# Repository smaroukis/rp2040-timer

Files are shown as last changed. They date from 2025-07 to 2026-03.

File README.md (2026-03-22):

# 10k-Hour-Timer-RP2040

An Eval Board for an RP2040 mcu + seven segment LED display + TM1638 driver + peripherals. 

## Project Structure

- `kicad/` - KiCad schematic and PCB design files
- `firmware/` - Firmware source code
- `datasheets/` - Component datasheets and documentation

## Hardware

This project uses the RP2040 microcontroller with supporting circuitry for power management, display drivers, and user interface components.
Note the firmware can be tested using a Raspberry Pi Pico board (original/v1 not Pico 2). 

## Getting Started

TODO - will post build log in the future.

## License

MIT License with other license files attached as used. 

## Hardware Revisions

### 2026-03-22 v1
Tagged commit: <link here>

Thanks to PCBWay for providing a partial discount which I put towards two pre-assemblied. Note that resistors R20 and R22 were populated with 220Ohms instead of 200Ohms as specified in the BOM. However these are just MOFSET gate protection resistors.

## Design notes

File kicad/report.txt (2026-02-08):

Plotted to '/home/spencer/Applications/KiCad/10k-Hour-Timer-RP2040/kicad/Fabrication_Outputs/2026-02-08-1134/10k-Hour-Timer-RP2040-F_Cu.gbr'.
Plotted to '/home/spencer/Applications/KiCad/10k-Hour-Timer-RP2040/kicad/Fabrication_Outputs/2026-02-08-1134/10k-Hour-Timer-RP2040-In1_Cu.gbr'.
Plotted to '/home/spencer/Applications/KiCad/10k-Hour-Timer-RP2040/kicad/Fabrication_Outputs/2026-02-08-1134/10k-Hour-Timer-RP2040-In2_Cu.gbr'.
Plotted to '/home/spencer/Applications/KiCad/10k-Hour-Timer-RP2040/kicad/Fabrication_Outputs/2026-02-08-1134/10k-Hour-Timer-RP2040-B_Cu.gbr'.
Plotted to '/home/spencer/Applications/KiCad/10k-Hour-Timer-RP2040/kicad/Fabrication_Outputs/2026-02-08-1134/10k-Hour-Timer-RP2040-F_Paste.gbr'.
Plotted to '/home/spencer/Applications/KiCad/10k-Hour-Timer-RP2040/kicad/Fabrication_Outputs/2026-02-08-1134/10k-Hour-Timer-RP2040-B_Paste.gbr'.
Plotted to '/home/spencer/Applications/KiCad/10k-Hour-Timer-RP2040/kicad/Fabrication_Outputs/2026-02-08-1134/10k-Hour-Timer-RP2040-F_Silkscreen.gbr'.
Plotted to '/home/spencer/Applications/KiCad/10k-Hour-Timer-RP2040/kicad/Fabrication_Outputs/2026-02-08-1134/10k-Hour-Timer-RP2040-B_Silkscreen.gbr'.
Plotted to '/home/spencer/Applications/KiCad/10k-Hour-Timer-RP2040/kicad/Fabrication_Outputs/2026-02-08-1134/10k-Hour-Timer-RP2040-F_Mask.gbr'.
Plotted to '/home/spencer/Applications/KiCad/10k-Hour-Timer-RP2040/kicad/Fabrication_Outputs/2026-02-08-1134/10k-Hour-Timer-RP2040-B_Mask.gbr'.
Plotted to '/home/spencer/Applications/KiCad/10k-Hour-Timer-RP2040/kicad/Fabrication_Outputs/2026-02-08-1134/10k-Hour-Timer-RP2040-Edge_Cuts.gbr'.
Created Gerber job file '/home/spencer/Applications/KiCad/10k-Hour-Timer-RP2040/kicad/Fabrication_Outputs/2026-02-08-1134/10k-Hour-Timer-RP2040-job.gbrjob'.
Info: Done.
Info: Done.

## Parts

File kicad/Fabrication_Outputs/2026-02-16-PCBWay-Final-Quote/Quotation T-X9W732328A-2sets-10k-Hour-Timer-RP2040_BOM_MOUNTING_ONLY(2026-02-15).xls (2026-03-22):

PCBWay Bom Quotation, Product No.:T-X9W732328A
Item # | *Designator | *Qty | Manufacturer | *Mfg Part # | Description / Value | Vendor Part # | *Package/Footprint | Your Instructions / Notes | *Unit Price(2 sets) | *Total | *Delivery Time | *Actual Purchase Mfg Part # | *PCBWay Note | Customer Reply | PCBWay Update
1 | C1 | 1 |  |  | 01A-USB『 』10n『 』Unpolarized capacitor |  | Capacitor_SMD:C_0603_1608Metric_Pad1.08x0.95mm_HandSolder『 』603 |  | $0.040 | $0.080 |  | CC0603KRX7R6BB103 |  | OK
2 | C2,C13,C15,C16,C18,C19,C21,C22,C24,C26,C28 | 11 |  |  | 01A-USB,05-MCU-XTAL-FLASH,06-MCU-IO,07-RTC,08-LED『 』100n『 』Unpolarized capacitor |  | Capacitor_SMD:C_0603_1608Metric_Pad1.08x0.95mm_HandSolder『 』603 |  | $0.006 | $0.132 |  | CC0603KRX7R9BB104 |  | OK
3 | C3,C4,C6,C25 | 4 |  | CL10A475KO8NNNC | Note for PCBA『 』02-DCDC,03-Charger,07-RTC『 』4.7u『 』Unpolarized capacitor | C19666 | Capacitor_SMD:C_0603_1608Metric_Pad1.08x0.95mm_HandSolder『 』603 | https://jlcpcb.com/partdetail/20375-CL10A475KO8NNNC/C19666 | $0.042 | $0.336
4 | C5 | 1 |  |  | 04-Batt-Prot『 』0.1u『 』Unpolarized capacitor |  | Capacitor_SMD:C_0603_1608Metric_Pad1.08x0.95mm_HandSolder『 』603 |  | $0.044 | $0.088 |  | CC0603KRX7R9BB104 |  | OK
5 | C7 | 1 |  |  | 02-DCDC『 』470n |  | Capacitor_SMD:C_0603_1608Metric_Pad1.08x0.95mm_HandSolder『 』603 |  | $0.118 | $0.236 |  | CC0603KRX7R8BB474 |  | OK
6 | C8 | 1 | Samsung Electro-Mechanics | CL10A226MQ8NRNC | 02-DCDC『 』22u『 』6.3V 22uF X5R ±20% 0603 Multilayer Ceramic Capacitors MLCC - SMD/SMT ROHS | LCSC『 』C59461 | Capacitor_SMD:C_0603_1608Metric_Pad1.08x0.95mm_HandSolder『 』603 | https://jlcpcb.com/partdetail/60514-CL10A226MQ8NRNC/C59461 | $0.172 | $0.344
7 | C9 | 1 |  |  | 02-DCDC『 』6.8p |  | Capacitor_SMD:C_0603_1608Metric_Pad1.08x0.95mm_HandSolder『 』603 |  | $0.033 | $0.066 |  | TCC0603COG6R8C500CT |  | OK
8 | C10,C11 | 2 |  |  | 05-MCU-XTAL-FLASH『 』15p『 』Unpolarized capacitor |  | Capacitor_SMD:C_0603_1608Metric_Pad1.08x0.95mm_HandSolder『 』603 |  | $0.023 | $0.092 |  | CC0603JRNPO9BN150 |  | OK
9 | C12 | 1 |  |  | 05-MCU-XTAL-FLASH『 』2.2u『 』Unpolarized capacitor |  | Capacitor_SMD:C_0603_1608Metric_Pad1.08x0.95mm_HandSolder『 』603 |  | $0.106 | $0.212 |  | CL10A225KP8NNNC |  | OK
10 | C14,C17,C20 | 3 |  |  | 05-MCU-XTAL-FLASH『 』1u『 』Unpolarized capacitor |  | Capacitor_SMD:C_0603_1608Metric_Pad1.08x0.95mm_HandSolder『 』603 |  | $0.022 | $0.132 |  | TCC0603X5R105K250CT |  | OK
11 | C23,C27 | 2 | Samsung Electro-Mechanics | CL31A107MQHNNNE | 08-LED『 』100u『 』Unpolarized capacitor | LCSC『 』C15008 | Capacitor_SMD:C_1206_3216Metric『 』1206 | https://lcsc.com/product-detail/Multilayer-Ceramic-Capacitors-MLCC-SMD-SMT_Samsung-Electro-Mechanics-CL31A107MQHNNNE_C15008.html | $0.264 | $1.056
12 | Y2 | 1 | Abracon LLC | ABS07AIG-32.768KHZ-7-T | 07-RTC『 』ABS07AIG-32.768KHZ-7-T『 』32.768 kHz ±20ppm 水晶振動子 7pF 80 kOhms 2-SMD、リードなし | Digikey『 』535-13350-1-ND | Crystal:Crystal_SMD_3215-2Pin_3.2x1.5mm『 』2-SMD（3.2x1.5） | https://www.digikey.jp/ja/products/detail/abracon-llc/ABS07AIG-32.768KHZ-7-T/5817604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 | $1.493 | $2.986 |  | ABS07AIG-32.768kHz-7-T |  | OK
13 | D4 | 1 | onsemi | SS14 (Generic) | 01A-Power-Mux『 』SS14『 』40V 1A Schottky Diode, SMA | Generic『 』C83852 | Diode_SMD:D_SMA『 』SMA(DO-214AC) | https://lcsc.com/product-detail/Schottky-Diodes_onsemi-SS14_C83852.html?s_z=n_ss14 | $0.255 | $0.510 |  | SS14 |  | OK
14 | D3 | 1 | Nexperia | PMEG1020EA,115 | 01A-Power-Mux『 』SOD-323『 』10V 460mV@2A 2A SOD-323 Schottky Diodes ROHS | LCSC『 』C426863 | Diode_SMD:D_SOD-323_HandSoldering『 』SOD-323 | https://lcsc.com/product-detail/Schottky-Diodes_Nexperia-PMEG1020EA-115_C426863.html | $0.429 | $0.858
15 | D1 | 1 | Hubei KENTO Elec | KT-0805G | 01A-Power-Mux『 』BATT『 』Light emitting diode, green | LCSC『 』C2297 | LED_SMD:LED_0805_2012Metric『 』805 | https://lcsc.com/product-detail/LED-Indication-Discrete_Hubei-KENTO-Elec-KT-0805G_C2297.html?s_z=n_KT-0805G | $0.051 | $0.102
16 | D2 | 1 | Hubei KENTO Elec | KT-0805G | 01A-Power-Mux『 』5V『 』Light emitting diode, green | LCSC『 』C2297 | LED_SMD:LED_0805_2012Metric『 』805 | https://lcsc.com/product-detail/LED-Indication-Discrete_Hubei-KENTO-Elec-KT-0805G_C2297.html?s_z=n_KT-0805G | $0.051 | $0.102
17 | D5 | 1 | Hubei KENTO Elec | KT-0805G | 03-Charger『 』GRN/DONE『 』Light emitting diode, green | LCSC『 』C2297 | LED_SMD:LED_0805_2012Metric『 』805 | https://lcsc.com/product-detail/LED-Indication-Discrete_Hubei-KENTO-Elec-KT-0805G_C2297.html?s_z=n_KT-0805G | $0.051 | $0.102
18 | D6 | 1 | Foshan NationStar Optoelectronics | NCD0805R1 | 03-Charger『 』RED/CHG『 』25mA 67mcd~195mcd -30℃~+85℃ 615nm~630nm Discrete Diode Red 130° 65mW 1.6V~2.6V 0805 LED Indication - Discrete ROHS | LCSC『 』C84256 | LED_SMD:LED_0805_2012Metric『 』805 | https://lcsc.com/product-detail/Light-Emitting-Diodes-LED_Foshan-NationStar-Optoelectronics-NCD0805R1_C84256.html | $0.040 | $0.080
19 | D8 | 1 | Hubei KENTO Elec | KT-0805G | 01A-Power-Mux『 』3V3『 』Light emitting diode | LCSC『 』C2297 | LED_SMD:LED_0805_2012Metric『 』805 | https://lcsc.com/product-detail/LED-Indication-Discrete_Hubei-KENTO-Elec-KT-0805G_C2297.html?s_z=n_KT-0805G | $0.051 | $0.102
20 | D9 | 1 | Foshan NationStar Optoelectronics | NCD0805R1 | 06-MCU-IO『 』RED/USER『 』25mA 67mcd~195mcd -30℃~+85℃ 615nm~630nm Discrete Diode Red 130° 65mW 1.6V~2.6V 0805 LED Indication - Discrete ROHS | LCSC『 』C84256 | LED_SMD:LED_0805_2012Metric『 』805 | https://lcsc.com/product-detail/Light-Emitting-Diodes-LED_Foshan-NationStar-Optoelectronics-NCD0805R1_C84256.html | $0.040 | $0.080
21 | D10 | 1 | Foshan NationStar Optoelectronics | NCD0805R1 | 07-RTC『 』RED/INT『 』25mA 67mcd~195mcd -30℃~+85℃ 615nm~630nm Discrete Diode Red 130° 65mW 1.6V~2.6V 0805 LED Indication - Discrete ROHS | LCSC『 』C84256 | LED_SMD:LED_0805_2012Metric『 』805 | https://lcsc.com/product-detail/Light-Emitting-Diodes-LED_Foshan-NationStar-Optoelectronics-NCD0805R1_C84256.html | $0.040 | $0.080
22 | U6 | 1 | Raspberry Pi | SC0914(13) | 05-MCU-XTAL-FLASH『 』RP2040『 』A microcontroller by Raspberry Pi | Digikey | Package_DFN_QFN:QFN-56-1EP_7x7mm_P0.4mm_EP3.2x3.2mm『 』QFN-56-1EP | https://www.digikey.jp/en/products/detail/raspberry-pi/SC0914-13/14306010 | $3.280 | $6.560 | 7-10 Workdays |  |  | Yes, confirmed actual part number is SC0914(13)
23 | U7 | 1 | NXP | PCF8523T/1,118 | 07-RTC『 』PCF8523T『 』Realtime Clock/Calendar I2C Interface, SOIC-8 | LCSC『 』C2651516 | Package_SO:SOIC-8_3.9x4.9mm_P1.27mm『 』SOP-8 | https://lcsc.com/product-detail/Real-Time-Clocks_NXP-PCF8523T-1-118_C2651516.html?s_z=n_PCF8523T | $3.735 | $7.470
24 | U5 | 1 | Winbond Elec | W25Q128JVSIQ | 05-MCU-XTAL-FLASH『 』W25Q128JVS『 』128Mbit / 16MiB Serial Flash Memory, Standard/Dual/Quad SPI, 2.7-3.6V, SOIC-8 | Digikey『 』C113767 | Package_SO:SOIC-8_5.3x5.3mm_P1.27mm『 』SOIC-8 | https://www.digikey.jp/en/products/detail/winbond-electronics/W25Q128JVSIQ/5803943『 』https://lcsc.com/product-detail/NOR-FLASH_Winbond-Elec-W25Q128JVSIQ_C113767.html?s_z=n_W25Q128JVS%2520 | $2.103 | $4.206
25 | U3 | 1 | Texas Instruments | BQ29700DSER | 04-Batt-Prot『 』BQ29700DSER『 』Voltage and Current Protection for Single-Cell Li-Ion and Li-Polymer Batteries | Digikey | Package_SON:WSON-6_1.5x1.5mm_P0.5mm『 』6-WSON | https://www.digikey.jp/en/products/detail/texas-instruments/BQ29700DSER/5973173 | $1.277 | $2.554
26 | D7 | 1 | onsemi | BAT54CLT1G | 02-DCDC『 』BAT54C『 』30V 1 pair of common cathodes 800mV@100mA 200mA SOT-23 Schottky Diodes ROHS | LCSC『 』C14308 | Package_TO_SOT_SMD:SOT-23『 』SOT-23 | https://jlcpcb.com/partdetail/onsemi-BAT54CLT1G/C14308 | $0.080 | $0.160
27 | Q1,Q6 | 2 | Vishay | SI2301CDS-T1-GE3 | 01A-Power-Mux,07-RTC『 』PMOS『 』20V 3.1A 1.6W 142mΩ@2.5V,2.7A 1V@250uA 1 P-Channel SOT-23 MOSFETs ROHS | LCSC『 』C10487 | Package_TO_SOT_SMD:SOT-23『 』SOT-23 | https://lcsc.com/product-detail/MOSFETs_Vishay-Intertech-SI2301CDS-T1-GE3_C10487.html?s_z=n_SI2301CDS-T1-GE3 | $0.110 | $0.440
28 | Q2,Q3,Q4,Q5,Q7,Q8 | 6 | Alpha & Omega Semicon | AO3400A | 04-Batt-Prot,06-MCU-IO『 』AO3400A『 』30V Vds, 5.7A Id, N-Channel MOSFET, SOT-23 | LCSC『 』C20917 | Package_TO_SOT_SMD:SOT-23『 』SOT-23 | https://jlcpcb.com/partdetail/Alpha_OmegaSemicon-AO3400A/C20917 | $0.094 | $1.128
29 | U2 | 1 | Microchip Technology | MCP73831T-2ACI/OT | 03-Charger『 』MCP73831-2-OT『 』Single cell, Li-Ion/Li-Po charge management controller, 4.20V, Tri-State Status Output, in SOT23-5 package | Digikey | Package_TO_SOT_SMD:SOT-23-5『 』SOT23-5 | https://www.digikey.jp/en/products/detail/microchip-technology/MCP73831T-2ACI-OT/964301 | $0.734 | $1.468
30 | U4 | 1 | Texas Instruments | TLV62568DBVR | 02-DCDC『 』TLV62568DBVR『 』IC REG BUCK ADJ 1A SOT23-5 | Digikey | Package_TO_SOT_SMD:SOT-23-5『 』SOT23-5 | https://www.digikey.jp/en/products/detail/texas-instruments/TLV62568DBVR/6588886 | $0.068 | $0.136
31 | FB1 | 1 | Murata | BLM18SP221SN1D | 01A-USB『 』BLM18SP221SN1D『 』Ferrite bead | Digikey | project footprints:BLM18SP221SN1D_BEADC1608X95N『 』603 | https://www.digikey.jp/en/products/detail/murata-electronics/BLM18SP221SN1D/12759416 | $1.088 | $2.176
32 | BZ2 | 1 | Murata | PKMCS0909E4000-R1 | DONT INCLUDE IN PCBA『 』06-MCU-IO『 』PKMCS0909E4000『 』Buzzers Transducer, Externally Driven Piezo 1.5 V 4kHz 65dB @ 1.5V, 10cm Surface Mount Solder Pads | Digikey | project footprints:Buzzer_SPKR_PKMCS0909E4000-R1 | https://www.digikey.jp/en/products/detail/murata-electronics/PKMCS0909E4000-R1/4878401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 | $1.213 | $2.426
33 | L1 | 1 | Cyntec | SDER041H-2R2MS | 02-DCDC『 』2.2uH『 』FIXED IND 2.2UH 3.1A 45MOHM SMD | Digikey | project footprints:IND_SDER041H-2R2MS『 』4mmx4mm | https://www.digikey.jp/en/products/detail/delta-electronics-cyntec/SDER041H-2R2MS/9761210 | $0.860 | $1.720 | 7-10 Workdays
34 | U10 | 1 | Titan Micro Electronics | TM1638 | 08-LED『 』TM1638『 』SOIC-28-300mil Digital Tube Drivers ROHS Seven Segment LED Driver | LCSC『 』C19187 | project footprints:SOIC127P1041X265-28N『 』SOIC-28-300mil | https://lcsc.com/product-detail/LED-Display-Drivers_TM-Shenzhen-Titan-Micro-Elec_C19187.html | $0.485 | $0.970
35 | Y1 | 1 | Abracon LLC | ABM8-272-T3 | 05-MCU-XTAL-FLASH『 』ABM8-272-T3『 』Four pin crystal, GND on pins 2 and 4 | LCSC『 』C20625731 | project footprints:XTAL_ABM8-272-T3『 』SMD3225-4P | https://lcsc.com/product-detail/Crystals_Abracon-LLC-ABM8-272-T3_C20625731.html?s_z=n_ABM8-272-T3%2520 | $1.095 | $2.190
36 | R4,R19,R21,R24,R25,R28,R34,R35,R36,R39,R40,R44,R45,R46,R47,R48,R49 | 17 |  |  | 01A-Power-Mux,05-MCU-XTAL-FLASH,06-MCU-IO『 』10K『 』Resistor |  | Resistor_SMD:R_0805_2012Metric_Pad1.20x1.40mm_HandSolder『 』805 |  | $0.004 | $0.136 |  | RC0805FR-0710KL
37 | R1,R2 | 2 |  |  | 01A-USB『 』5.1K『 』Resistor |  | Resistor_SMD:R_0805_2012Metric_Pad1.20x1.40mm_HandSolder『 』805 |  | $0.019 | $0.076 |  | 0805W8F5101T5E
38 | R3,R14,R23,R26,R32,R38,R41 | 7 |  |  | 02-DCDC,04-Batt-Prot,05-MCU-XTAL-FLASH,06-MCU-IO,07-RTC『 』1K『 』Resistor |  | Resistor_SMD:R_0805_2012Metric_Pad1.20x1.40mm_HandSolder『 』805 |  | $0.007 | $0.098 |  | RC0805FR-071KL
39 | R5,R7,R8,R18 | 4 |  |  | 01A-Power-Mux,03-Charger『 』2K『 』Resistor |  | Resistor_SMD:R_0805_2012Metric_Pad1.20x1.40mm_HandSolder『 』805 |  | $0.009 | $0.072 |  | 0805W8F2001T5E
40 | R6 | 1 |  |  | 03-Charger『 』3K『 』Resistor |  | Resistor_SMD:R_0805_2012Metric_Pad1.20x1.40mm_HandSolder『 』805 |  | $0.033 | $0.066 |  | 0805W8F3001T5E
41 | R9 | 1 |  |  | 04-Batt-Prot『 』0『 』Resistor |  | Resistor_SMD:R_0805_2012Metric_Pad1.20x1.40mm_HandSolder『 』805 |  | $0.038 | $0.076 |  | 0805W8F0000T5E |  | 0805W8F0000T5E
42 | R10 | 1 |  |  | 04-Batt-Prot『 』330『 』Resistor |  | Resistor_SMD:R_0805_2012Metric_Pad1.20x1.40mm_HandSolder『 』805 |  | $0.026 | $0.052 |  | 0805W8F3300T5E |  | 0805W8F3300T5E
43 | R11 | 1 |  |  | 04-Batt-Prot『 』2.2K『 』Resistor |  | Resistor_SMD:R_0805_2012Metric_Pad1.20x1.40mm_HandSolder『 』805 |  | $0.038 | $0.076 |  | RC0805FR-072K2L
44 | R12,R13 | 2 |  |  | 04-Batt-Prot『 』5.1M『 』Resistor |  | Resistor_SMD:R_0805_2012Metric_Pad1.20x1.40mm_HandSolder『 』805 |  | $0.015 | $0.060 |  | 0805W8F5104T5E
45 | R15,R43 | 2 |  |  | 02-DCDC,07-RTC『 』100K『 』Resistor |  | Resistor_SMD:R_0805_2012Metric_Pad1.20x1.40mm_HandSolder『 』805 |  | $0.012 | $0.048 |  | 0805W8F1003T5E
46 | R16 | 1 |  |  | 02-DCDC『 』200K『 』Resistor |  | Resistor_SMD:R_0805_2012Metric_Pad1.20x1.40mm_HandSolder『 』805 |  | $0.024 | $0.048 |  | 0805W8F2003T5E
47 | R17 | 1 |  |  | 02-DCDC『 』44.2K『 』Resistor |  | Resistor_SMD:R_0805_2012Metric_Pad1.20x1.40mm_HandSolder『 』805 |  | $0.150 | $0.300 |  | 0805W8F4422T5E
48 | R20,R22 | 2 |  |  | 06-MCU-IO『 』200『 』Resistor |  | Resistor_SMD:R_0805_2012Metric_Pad1.20x1.40mm_HandSolder『 』805 |  | $0.018 | $0.072 |  | 0805W8F2200T5E |  | 0805W8F2200T5E
49 | R27,R29 | 2 |  |  | 06-MCU-IO『 』27『 』Resistor |  | Resistor_SMD:R_0805_2012Metric_Pad1.20x1.40mm_HandSolder『 』805 |  | $0.012 | $0.048 |  | 0805W8F270JT5E |  | 0805W8F270JT5E
50 | R30,R31 | 2 |  |  | 05-MCU-XTAL-FLASH『 』100『 』Resistor |  | Resistor_SMD:R_0805_2012Metric_Pad1.20x1.40mm_HandSolder『 』805 |  | $0.017 | $0.068 |  | 0805W8F1000T5E |  | 0805W8F1000T5E
51 | R33 | 1 |  |  | 05-MCU-XTAL-FLASH『 』1『 』Resistor |  | Resistor_SMD:R_0805_2012Metric_Pad1.20x1.40mm_HandSolder『 』805 |  |  |  |  |  | [DNP不要贴]; | Do Not Populate
52 | R37,R42 | 2 |  |  | 06-MCU-IO,07-RTC『 』470『 』Resistor |  | Resistor_SMD:R_0805_2012Metric_Pad1.20x1.40mm_HandSolder『 』805 |  | $0.016 | $0.064 |  | 0805W8F4700T5E |  | 0805W8F4700T5E
 |  |  |  |  |  |  |  |  | Component Cost | $42.74

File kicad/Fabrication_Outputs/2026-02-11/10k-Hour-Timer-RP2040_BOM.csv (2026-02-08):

Subsystem | Reference | Lab_In_Stock | Value | DNP | Exclude from BOM | Exclude from Board | Footprint | Description | Manufacturer | MPN | Supplier 1 | Supplier 1 URL | Supplier 1 SKU | Package | Supplier 2 URL | Supplier 2 | Supplier 2 SKU
 | BOM1 |  | JST PH 2.0mm Connector Kit | DNP | Excluded from BOM | Excluded from board |  | For Board Auxiliary order items - connectors, batteries, etc |  |  | Digikey | https://www.digikey.jp/en/products/detail/adafruit-industries-llc/4422/11497499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
 | BOM2 |  | Crimp Pliers for JST-PH connectors | DNP | Excluded from BOM | Excluded from board |  | Micro terminal crimper down to 1.0mm barrel width. Works well for JST-PH - use the 1.4mm or 1.6mm barrel size. | Engineer | PA-09 | Amazon | https://www.amazon.co.jp/-/en/Engineer-Precision-Crimping-Terminals-PA-09/dp/B002AVVO7K/ref=sr_1_2
 | BOM3 |  | Coin Vibration Motor 3V | DNP | Excluded from BOM | Excluded from board |  | 9000rpm Flat Vibration Motor 3V Vibration Motors ROHS 6mm | Leader | LCM0720A3134F | LCSC | https://lcsc.com/product-detail/Vibration-Motors_LEADER-LCM0720A3134F_C2895081.html | C2895081
05-MCU-XTAL-FLASH | SW1 | Y | B3U-1100PM | DNP | Excluded from BOM | Excluded from board | Button_Switch_SMD:SW_SPST_B3U-1100P | SWITCH TACTILE SPST-NO 0.05A 12V | omron | B3U-1100PM | Digikey | https://www.digikey.jp/en/products/detail/omron-electronics-inc-emc-div/B3U-1100PM/3908607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 |  | SMD 4mmx2.5mm
04-Batt-Prot | SW6 | THS | SW_SPDT | DNP |  |  | Button_Switch_THT:SW_E-Switch_EG1271_SPDT | Switch, single pole double throw | E-Switch | EG1271 | Digikey | https://www.digikey.com/en/products/detail/e-switch/EG1271/251335
05-MCU-XTAL-FLASH | SW2 | Y | BOOTSEL | DNP |  |  | Button_Switch_THT:SW_PUSH_6mm | Push button switch, generic, two pins | (Generic)/TE | (Generic)/1825910-6 | (Generic)/Digikey | https://www.digikey.jp/en/products/detail/te-connectivity-alcoswitch-switches/1825910-6/1632536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
05-MCU-XTAL-FLASH | SW3 | Y | RESET | DNP |  |  | Button_Switch_THT:SW_PUSH_6mm | Push button switch, generic, two pins | (Generic)/TE | (Generic)/1825910-6 | (Generic)/Digikey | https://www.digikey.jp/en/products/detail/te-connectivity-alcoswitch-switches/1825910-6/1632536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
06-MCU-IO | SW4 | Y | USER_A | DNP |  |  | Button_Switch_THT:SW_PUSH_6mm | Push button switch, generic, two pins | (Generic)/TE | (Generic)/1825910-6 | (Generic)/Digikey | https://www.digikey.jp/en/products/detail/te-connectivity-alcoswitch-switches/1825910-6/1632536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 |  | PB_6x6
06-MCU-IO | SW5 | Y | USER_B_PWR | DNP |  |  | Button_Switch_THT:SW_PUSH_6mm | Push button switch, generic, two pins | (Generic)/TE | (Generic)/1825910-6 | (Generic)/Digikey | https://www.digikey.jp/en/products/detail/te-connectivity-alcoswitch-switches/1825910-6/1632536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 |  | PB_6x6
01A-USB | C1 | Y | 10n |  |  |  | Capacitor_SMD:C_0603_1608Metric_Pad1.08x0.95mm_HandSolder | Unpolarized capacitor | (Generic) | (Generic) | (Generic) |  |  | 0603
01A-USB,05-MCU-XTAL-FLASH,06-MCU-IO,07-RTC,08-LED | C2,C13,C15,C16,C18,C19,C21,C22,C24,C26,C28 | Y | 100n |  |  |  | Capacitor_SMD:C_0603_1608Metric_Pad1.08x0.95mm_HandSolder | Unpolarized capacitor | (Generic) | (Generic) | (Generic) |  |  | 0603
02-DCDC,03-Charger,07-RTC | C3,C4,C6,C25 | Y | 4.7u |  |  |  | Capacitor_SMD:C_0603_1608Metric_Pad1.08x0.95mm_HandSolder | Unpolarized capacitor | (Generic) | (Generic) | (Generic) | https://jlcpcb.com/partdetail/20375-CL10A475KO8NNNC/C19666 | C19666 | 0603
04-Batt-Prot | C5 | Y | 0.1u |  |  |  | Capacitor_SMD:C_0603_1608Metric_Pad1.08x0.95mm_HandSolder | Unpolarized capacitor | (Generic) | (Generic) | (Generic) |  |  | 0603
02-DCDC | C7 | Y | 470n |  |  |  | Capacitor_SMD:C_0603_1608Metric_Pad1.08x0.95mm_HandSolder |  | (Generic) | (Generic) | (Generic) |  |  | 0603
02-DCDC | C8 |  | 22u |  |  |  | Capacitor_SMD:C_0603_1608Metric_Pad1.08x0.95mm_HandSolder | 6.3V 22uF X5R ±20% 0603 Multilayer Ceramic Capacitors MLCC - SMD/SMT ROHS | Samsung Electro-Mechanics | CL10A226MQ8NRNC | LCSC | https://jlcpcb.com/partdetail/60514-CL10A226MQ8NRNC/C59461 | C59461 | 0603
02-DCDC | C9 | Y | 6.8p |  |  |  | Capacitor_SMD:C_0603_1608Metric_Pad1.08x0.95mm_HandSolder |  | (Generic) | (Generic) | (Generic) |  |  | 0603
05-MCU-XTAL-FLASH | C10,C11 | Y | 15p |  |  |  | Capacitor_SMD:C_0603_1608Metric_Pad1.08x0.95mm_HandSolder | Unpolarized capacitor | (Generic) | (Generic) | (Generic) |  |  | 0603
05-MCU-XTAL-FLASH | C12 | Y | 2.2u |  |  |  | Capacitor_SMD:C_0603_1608Metric_Pad1.08x0.95mm_HandSolder | Unpolarized capacitor | (Generic) | (Generic) | (Generic) |  |  | 0603
05-MCU-XTAL-FLASH | C14,C17,C20 | Y | 1u |  |  |  | Capacitor_SMD:C_0603_1608Metric_Pad1.08x0.95mm_HandSolder | Unpolarized capacitor | (Generic) | (Generic) | (Generic) |  |  | 0603
08-LED | C23,C27 |  | 100u |  |  |  | Capacitor_SMD:C_1206_3216Metric | Unpolarized capacitor | Samsung Electro-Mechanics | CL31A107MQHNNNE | LCSC | https://lcsc.com/product-detail/Multilayer-Ceramic-Capacitors-MLCC-SMD-SMT_Samsung-Electro-Mechanics-CL31A107MQHNNNE_C15008.html | C15008 | 1206
02-DCDC,04-Batt-Prot | J4,J10 | Y | S2B-PH-K-S_LF__SN_ | DNP |  |  | Connector_JST:JST_PH_S2B-PH-K_1x02_P2.00mm_Horizontal | CONN HEADER R/A 2POS 2MM | JST | S2B-PH-K-S | Digikey | https://www.digikey.jp/en/products/detail/jst-sales-america-inc/S2B-PH-K-S/926626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 |  | NON STANDARD-2 J.S.T.
07-RTC | J9,J11 | Y | Conn_01x02_Pin | DNP |  |  | Connector_PinHeader_2.54mm:PinHeader_1x02_P2.54mm_Vertical | Generic connector, single row, 01x02, script generated
05-MCU-XTAL-FLASH,06-MCU-IO | J1,J7,J8 | Y | Conn_01x03_Pin | DNP |  |  | Connector_PinHeader_2.54mm:PinHeader_1x03_P2.54mm_Vertical | Generic connector, single row, 01x03, script generated | (Embedded) | (Embedded) | (Embedded)
06-MCU-IO | J5 | Y | Conn_02x05_Counter_Clockwise | DNP |  |  | Connector_PinHeader_2.54mm:PinHeader_2x05_P2.54mm_Vertical | Generic connector, double row, 02x05, odd/even pin numbering scheme (row 1 odd numbers, row 2 even numbers), script generated (kicad-library-utils/schlib/autogen/connector/)
 | J6 | Y | Conn_02x08_Counter_Clockwise | DNP |  |  | Connector_PinHeader_2.54mm:PinHeader_2x08_P2.54mm_Vertical | Generic connector, double row, 02x08, odd/even pin numbering scheme (row 1 odd numbers, row 2 even numbers), script generated (kicad-library-utils/schlib/autogen/connector/)
07-RTC | Y2 |  | ABS07AIG-32.768KHZ-7-T |  |  |  | Crystal:Crystal_SMD_3215-2Pin_3.2x1.5mm | 32.768 kHz ±20ppm 水晶振動子 7pF 80 kOhms 2-SMD、リードなし | Abracon LLC | ABS07AIG-32.768KHZ-7-T | Digikey | https://www.digikey.jp/ja/products/detail/abracon-llc/ABS07AIG-32.768KHZ-7-T/5817604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 | 535-13350-1-ND | 2-SMD（3.2x1.5）
01A-Power-Mux | D4 |  | SS14 |  |  |  | Diode_SMD:D_SMA | 40V 1A Schottky Diode, SMA | onsemi | SS14 (Generic) | Generic | https://lcsc.com/product-detail/Schottky-Diodes_onsemi-SS14_C83852.html?s_z=n_ss14 | C83852 | SMA(DO-214AC)
01A-Power-Mux | D3 |  | SOD-323 |  |  |  | Diode_SMD:D_SOD-323_HandSoldering | 10V 460mV@2A 2A SOD-323 Schottky Diodes ROHS | Nexperia | PMEG1020EA,115 | LCSC | https://lcsc.com/product-detail/Schottky-Diodes_Nexperia-PMEG1020EA-115_C426863.html | C426863 | SOD-323
01A-Power-Mux,06-MCU-IO | JP2,JP4,JP7,JP9,JP11,JP13,JP16,JP17,JP18,JP19,JP20 |  | SolderJumper_2_Bridged |  | Excluded from BOM |  | Jumper:SolderJumper-2_P1.3mm_Bridged_RoundedPad1.0x1.5mm | Solder Jumper, 2-pole, closed/bridged |  | (Embedded)
01A-Power-Mux,01A-USB,07-RTC | JP1,JP3,JP5,JP6,JP10,JP12,JP21,JP22,JP23,JP24 |  | SolderJumper_2_Open |  | Excluded from BOM |  | Jumper:SolderJumper-2_P1.3mm_Open_RoundedPad1.0x1.5mm | Solder Jumper, 2-pole, open |  | (Embedded)
 | JP8 |  | SolderJumper_3_Bridged12 |  | Excluded from BOM |  | Jumper:SolderJumper-3_P1.3mm_Bridged12_RoundedPad1.0x1.5mm | 3-pole Solder Jumper, pins 1+2 closed/bridged
01A-Power-Mux | D1 |  | BATT |  |  |  | LED_SMD:LED_0805_2012Metric | Light emitting diode | Hubei KENTO Elec | KT-0805G | LCSC | https://lcsc.com/product-detail/LED-Indication-Discrete_Hubei-KENTO-Elec-KT-0805G_C2297.html?s_z=n_KT-0805G | C2297 | 0805
01A-Power-Mux | D2 |  | 5V |  |  |  | LED_SMD:LED_0805_2012Metric | Light emitting diode | Hubei KENTO Elec | KT-0805G | LCSC | https://lcsc.com/product-detail/LED-Indication-Discrete_Hubei-KENTO-Elec-KT-0805G_C2297.html?s_z=n_KT-0805G | C2297 | 0805
03-Charger | D5 |  | GRN/DONE |  |  |  | LED_SMD:LED_0805_2012Metric | Light emitting diode | Hubei KENTO Elec | KT-0805G | LCSC | https://lcsc.com/product-detail/LED-Indication-Discrete_Hubei-KENTO-Elec-KT-0805G_C2297.html?s_z=n_KT-0805G | C2297 | 0805
03-Charger | D6 |  | RED/CHG |  |  |  | LED_SMD:LED_0805_2012Metric | 25mA 67mcd~195mcd -30℃~+85℃ 615nm~630nm Discrete Diode Red 130° 65mW 1.6V~2.6V 0805 LED Indication - Discrete ROHS | Foshan NationStar Optoelectronics | NCD0805R1 | LCSC | https://lcsc.com/product-detail/Light-Emitting-Diodes-LED_Foshan-NationStar-Optoelectronics-NCD0805R1_C84256.html | C84256 | 0805
01A-Power-Mux | D8 |  | 3V3 |  |  |  | LED_SMD:LED_0805_2012Metric | Light emitting diode | Hubei KENTO Elec | KT-0805G | LCSC | https://lcsc.com/product-detail/LED-Indication-Discrete_Hubei-KENTO-Elec-KT-0805G_C2297.html?s_z=n_KT-0805G | C2297 | 0805
06-MCU-IO | D9 |  | RED/USER |  |  |  | LED_SMD:LED_0805_2012Metric | 25mA 67mcd~195mcd -30℃~+85℃ 615nm~630nm Discrete Diode Red 130° 65mW 1.6V~2.6V 0805 LED Indication - Discrete ROHS | Foshan NationStar Optoelectronics | NCD0805R1 | LCSC | https://lcsc.com/product-detail/Light-Emitting-Diodes-LED_Foshan-NationStar-Optoelectronics-NCD0805R1_C84256.html | C84256 | 0805
07-RTC | D10 |  | RED/INT |  |  |  | LED_SMD:LED_0805_2012Metric | 25mA 67mcd~195mcd -30℃~+85℃ 615nm~630nm Discrete Diode Red 130° 65mW 1.6V~2.6V 0805 LED Indication - Discrete ROHS | Foshan NationStar Optoelectronics | NCD0805R1 | LCSC | https://lcsc.com/product-detail/Light-Emitting-Diodes-LED_Foshan-NationStar-Optoelectronics-NCD0805R1_C84256.html | C84256 | 0805
05-MCU-XTAL-FLASH | U6 |  | RP2040 |  |  |  | Package_DFN_QFN:QFN-56-1EP_7x7mm_P0.4mm_EP3.2x3.2mm | A microcontroller by Raspberry Pi | Raspberry Pi | SC0914(13) | Digikey | https://www.digikey.jp/en/products/detail/raspberry-pi/SC0914-13/14306010 |  | QFN-56-1EP
07-RTC | U7 |  | PCF8523T |  |  |  | Package_SO:SOIC-8_3.9x4.9mm_P1.27mm | Realtime Clock/Calendar I2C Interface, SOIC-8 | NXP | PCF8523T/1,118 | LCSC | https://lcsc.com/product-detail/Real-Time-Clocks_NXP-PCF8523T-1-118_C2651516.html?s_z=n_PCF8523T | C2651516 | SOP-8
05-MCU-XTAL-FLASH | U5 |  | W25Q128JVS |  |  |  | Package_SO:SOIC-8_5.3x5.3mm_P1.27mm | 128Mbit / 16MiB Serial Flash Memory, Standard/Dual/Quad SPI, 2.7-3.6V, SOIC-8 | Winbond Elec | W25Q128JVSIQ | Digikey | https://www.digikey.jp/en/products/detail/winbond-electronics/W25Q128JVSIQ/5803943 |  | SOIC-8 | https://lcsc.com/product-detail/NOR-FLASH_Winbond-Elec-W25Q128JVSIQ_C113767.html?s_z=n_W25Q128JVS%2520 | LCSC | C113767
04-Batt-Prot | U3 |  | BQ29700DSER |  |  |  | Package_SON:WSON-6_1.5x1.5mm_P0.5mm | Voltage and Current Protection for Single-Cell Li-Ion and Li-Polymer Batteries | Texas Instruments | BQ29700DSER | Digikey | https://www.digikey.jp/en/products/detail/texas-instruments/BQ29700DSER/5973173 |  | 6-WSON
02-DCDC | D7 |  | BAT54C |  |  |  | Package_TO_SOT_SMD:SOT-23 | 30V 1 pair of common cathodes 800mV@100mA 200mA SOT-23 Schottky Diodes ROHS | onsemi | BAT54CLT1G | LCSC | https://jlcpcb.com/partdetail/onsemi-BAT54CLT1G/C14308 | C14308 | SOT-23
01A-Power-Mux,07-RTC | Q1,Q6 |  | PMOS |  |  |  | Package_TO_SOT_SMD:SOT-23 | 20V 3.1A 1.6W 142mΩ@2.5V,2.7A 1V@250uA 1 P-Channel SOT-23 MOSFETs ROHS | Vishay | SI2301CDS-T1-GE3 | LCSC | https://lcsc.com/product-detail/MOSFETs_Vishay-Intertech-SI2301CDS-T1-GE3_C10487.html?s_z=n_SI2301CDS-T1-GE3 | C10487 | SOT-23
04-Batt-Prot,06-MCU-IO | Q2,Q3,Q4,Q5,Q7,Q8 |  | AO3400A |  |  |  | Package_TO_SOT_SMD:SOT-23 | 30V Vds, 5.7A Id, N-Channel MOSFET, SOT-23 | Alpha & Omega Semicon | AO3400A | LCSC | https://jlcpcb.com/partdetail/Alpha_OmegaSemicon-AO3400A/C20917 | C20917 | SOT-23
03-Charger | U2 |  | MCP73831-2-OT |  |  |  | Package_TO_SOT_SMD:SOT-23-5 | Single cell, Li-Ion/Li-Po charge management controller, 4.20V, Tri-State Status Output, in SOT23-5 package | Microchip Technology | MCP73831T-2ACI/OT | Digikey | https://www.digikey.jp/en/products/detail/microchip-technology/MCP73831T-2ACI-OT/964301 |  | SOT23-5
02-DCDC | U4 |  | TLV62568DBVR |  |  |  | Package_TO_SOT_SMD:SOT-23-5 | IC REG BUCK ADJ 1A SOT23-5 | Texas Instruments | TLV62568DBVR | Digikey | https://www.digikey.jp/en/products/detail/texas-instruments/TLV62568DBVR/6588886 |  | SOT23-5
01A-USB | U1 |  | USBLC6-2SC6 | DNP | Excluded from BOM | Excluded from board | Package_TO_SOT_SMD:SOT-23-6 | Very low capacitance ESD protection diode, 2 data-line, SOT-23-6 | ST Microelectronics | USBLC6-2SC6 | LCSC | https://lcsc.com/product-detail/ESD-and-Surge-Protection-TVS-ESD_STMicroelectronics-USBLC6-2SC6_C7519.html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 | C7519
08-LED | U8,U9 | Y | FJ2481CH | DNP |  |  | project footprints:7-Seg-CC28-FJ2481CH | 4 digit 7 segment red LED, common cathode 0.28" height 2.54mm pitch | Shenzhen Zhihao Elec | FJ2481CH | LCSC | https://lcsc.com/product-detail/LED-Segment-Displays_Shenzhen-Zhihao-Elec-FJ2481CH_C10707.html | C10707
04-Batt-Prot | BT1 | Y | Battery_Cell | DNP |  |  | project footprints:Battery-Holder-BH-123A_37.5P_1.8D_MH | Battery Holder 1 Cells Polypropylene Tray | MYOUNG | BH-123A-A1CJ002 | LCSC
01A-USB | FB1 | Y | BLM18SP221SN1D |  |  |  | project footprints:BLM18SP221SN1D_BEADC1608X95N | Ferrite bead | Murata | BLM18SP221SN1D | Digikey | https://www.digikey.jp/en/products/detail/murata-electronics/BLM18SP221SN1D/12759416 |  | 0603
06-MCU-IO | BZ1 | Y | Buzzer D=9mm P=5mm | DNP |  |  | project footprints:Buzzer-TH_D9.6_P5 | 85dB Active (Built-in Driver Circuit) Electromagnetic Type 3kHz Plugin,D=9mm Buzzers ROHS | Jiangsu Huaneng Elec | HNB09A05 | LCSC | https://lcsc.com/product-detail/Buzzers_Jiangsu-Huaneng-Elec-HNB09A05_C96493.html | C96493 | BZ_THT_D9.6_P5
06-MCU-IO | BZ2 |  | PKMCS0909E4000 |  |  |  | project footprints:Buzzer_SPKR_PKMCS0909E4000-R1 | Buzzers Transducer, Externally Driven Piezo 1.5 V 4kHz 65dB @ 1.5V, 10cm Surface Mount Solder Pads | Murata | PKMCS0909E4000-R1 | Digikey | https://www.digikey.jp/en/products/detail/murata-electronics/PKMCS0909E4000-R1/4878401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
01A-USB | J3 | Y | USB4105-GF-A | DNP |  |  | project footprints:GCT_USB4105-GF-A | CONN RCP USB2.0 TYP C 24P SMD RA | GCT | USB4105-GF-A | Digikey | https://www.digikey.jp/en/products/detail/gct/USB4105-GF-A/11198441 | 2073-USB4105-GF-ACT-ND
02-DCDC | L1 |  | 2.2uH |  |  |  | project footprints:IND_SDER041H-2R2MS | FIXED IND 2.2UH 3.1A 45MOHM SMD | Cyntec | SDER041H-2R2MS | Digikey | https://www.digikey.jp/en/products/detail/delta-electronics-cyntec/SDER041H-2R2MS/9761210 |  | 4mmx4mm
05-MCU-XTAL-FLASH | J2 |  | JST_SH_SM03B | DNP |  |  | project footprints:JST_SH_SM03B-SRSS-TB_1x03-1MP_P1.00mm_Horizontal | Generic connectable mounting pin connector, single row, 01x03, script generated (kicad-library-utils/schlib/autogen/connector/) | JST | SM03B-SRSS-TB(LF)(SN) | LCSC | https://lcsc.com/product-detail/Wire-To-Board-Connector_JST-SM03B-SRSS-TB-LF-SN_C160403.html | C160403
 | H1,H2,H3,H4 | Y | MH-4.7mm |  | Excluded from BOM |  | project footprints:MountingHole_4.7mm | BOARD SUPRT SNAP FIT NYLON 4.7mm hole,Mounting Hole without connection | Keystone | 8834 | Digikey | https://www.digikey.jp/en/products/detail/keystone-electronics/8834/317168 |  | D4.7mm
08-LED | U10 | Y | TM1638 |  |  |  | project footprints:SOIC127P1041X265-28N | SOIC-28-300mil Digital Tube Drivers ROHS Seven Segment LED Driver | Titan Micro Electronics | TM1638 | LCSC | https://lcsc.com/product-detail/LED-Display-Drivers_TM-Shenzhen-Titan-Micro-Elec_C19187.html | C19187 | SOIC-28-300mil
01A-USB,04-Batt-Prot | TP1,TP13 |  | GND |  |  |  | project footprints:TestPoint_THTPad_D2.0mm_Drill1.0mm | test point |  | (Embedded)
01A-USB | TP2 |  | VBUS_IN |  |  |  | project footprints:TestPoint_THTPad_D2.0mm_Drill1.0mm | test point |  | (Embedded)
01A-USB | TP3 |  | VBUS |  |  |  | project footprints:TestPoint_THTPad_D2.0mm_Drill1.0mm | test point |  | (Embedded)
01A-Power-Mux | TP4 |  | VBAT |  |  |  | project footprints:TestPoint_THTPad_D2.0mm_Drill1.0mm | test point |  | (Embedded)
 | TP5 |  | U2_VDD |  |  |  | project footprints:TestPoint_THTPad_D2.0mm_Drill1.0mm | test point |  | (Embedded)
01A-Power-Mux | TP6 |  | VSW |  |  |  | project footprints:TestPoint_THTPad_D2.0mm_Drill1.0mm | test point |  | (Embedded)
 | TP7 |  | STAT |  |  |  | project footprints:TestPoint_THTPad_D2.0mm_Drill1.0mm | test point |  | (Embedded)
04-Batt-Prot | TP8 |  | BAT+ |  |  |  | project footprints:TestPoint_THTPad_D2.0mm_Drill1.0mm | test point |  | (Embedded)
04-Batt-Prot | TP9,TP15 |  | BAT- |  |  |  | project footprints:TestPoint_THTPad_D2.0mm_Drill1.0mm | test point |  | (Embedded)
04-Batt-Prot | TP10 |  | U3_V- |  |  |  | project footprints:TestPoint_THTPad_D2.0mm_Drill1.0mm | test point |  | (Embedded)
04-Batt-Prot | TP11 |  | DSG |  |  |  | project footprints:TestPoint_THTPad_D2.0mm_Drill1.0mm | test point |  | (Embedded)
 | TP12 |  | CHG |  |  |  | project footprints:TestPoint_THTPad_D2.0mm_Drill1.0mm | test point |  | (Embedded)
04-Batt-Prot | TP14 |  | Q23_D |  |  |  | project footprints:TestPoint_THTPad_D2.0mm_Drill1.0mm | test point |  | (Embedded)
 | TP16 |  | EN_CTL |  |  |  | project footprints:TestPoint_THTPad_D2.0mm_Drill1.0mm | test point |  | (Embedded)
 | TP17 |  | DC_SW |  |  |  | project footprints:TestPoint_THTPad_D2.0mm_Drill1.0mm | test point |  | (Embedded)
06-MCU-IO | TP18 |  | IOGate |  |  |  | project footprints:TestPoint_THTPad_D2.0mm_Drill1.0mm | test point |  | (Embedded)
 | TP19 |  | DCDC_EN |  |  |  | project footprints:TestPoint_THTPad_D2.0mm_Drill1.0mm | test point |  | (Embedded)
06-MCU-IO | TP20 |  | ADC1 |  |  |  | project footprints:TestPoint_THTPad_D2.0mm_Drill1.0mm | test point |  | (Embedded)
06-MCU-IO | TP21 |  | BTN_B |  |  |  | project footprints:TestPoint_THTPad_D2.0mm_Drill1.0mm | test point |  | (Embedded)
06-MCU-IO | TP22 |  | BTN_B_IN |  |  |  | project footprints:TestPoint_THTPad_D2.0mm_Drill1.0mm | test point |  | (Embedded)
 | TP23 |  | ADC0 |  |  |  | project footprints:TestPoint_THTPad_D2.0mm_Drill1.0mm | test point |  | (Embedded)
 | TP24 |  | INT_G |  |  |  | project footprints:TestPoint_THTPad_D2.0mm_Drill1.0mm | test point |  | (Embedded)
 | TP25 |  | INT_D |  |  |  | project footprints:TestPoint_THTPad_D2.0mm_Drill1.0mm | test point |  | (Embedded)
 | TP26 |  | LOAD |  |  |  | project footprints:TestPoint_THTPad_D2.0mm_Drill1.0mm | test point |  | (Embedded)
 | TP27 |  | FB |  |  |  | project footprints:TestPoint_THTPad_D2.0mm_Drill1.0mm | test point |  | (Embedded)
01A-USB | J12 |  | USB_C_Receptacle_USB2.0_16P | DNP | Excluded from BOM | Excluded from board | project footprints:USB_C_Receptacle_JAE_DX07S016JA1R1500 | USB 2.0-only 16P Type-C Receptacle connector | JAE Electronics | DX07S016JA1R1500 | LCSC | https://lcsc.com/product-detail/USB-Connectors_JAE-Electronics-DX07S016JA1R1500_C3197885.html | C3197885
05-MCU-XTAL-FLASH | Y1 |  | ABM8-272-T3 |  |  |  | project footprints:XTAL_ABM8-272-T3 | Four pin crystal, GND on pins 2 and 4 | Abracon LLC | ABM8-272-T3 | LCSC | https://lcsc.com/product-detail/Crystals_Abracon-LLC-ABM8-272-T3_C20625731.html?s_z=n_ABM8-272-T3%2520 | C20625731 | SMD3225-4P
01A-USB | R1,R2 |  | 5.1K |  |  |  | Resistor_SMD:R_0805_2012Metric_Pad1.20x1.40mm_HandSolder | Resistor | (Generic) | (Generic) | (Generic) |  |  | 0805
02-DCDC,04-Batt-Prot,05-MCU-XTAL-FLASH,06-MCU-IO,07-RTC | R3,R14,R23,R26,R32,R38,R41 |  | 1K |  |  |  | Resistor_SMD:R_0805_2012Metric_Pad1.20x1.40mm_HandSolder | Resistor | (Generic) | (Generic) | (Generic) |  |  | 0805
01A-Power-Mux,05-MCU-XTAL-FLASH,06-MCU-IO | R4,R19,R21,R24,R25,R28,R34,R35,R36,R39,R40,R44,R45,R46,R47,R48,R49 |  | 10K | DNP |  |  | Resistor_SMD:R_0805_2012Metric_Pad1.20x1.40mm_HandSolder | Resistor | (Generic) | (Generic) | (Generic) |  |  | 0805
01A-Power-Mux,03-Charger | R5,R7,R8,R18 |  | 2K |  |  |  | Resistor_SMD:R_0805_2012Metric_Pad1.20x1.40mm_HandSolder | Resistor | (Generic) | (Generic) | (Generic) |  |  | 0805
03-Charger | R6 |  | 3K |  |  |  | Resistor_SMD:R_0805_2012Metric_Pad1.20x1.40mm_HandSolder | Resistor | (Generic) | (Generic) | (Generic) |  |  | 0805
04-Batt-Prot | R9 |  | 0 |  |  |  | Resistor_SMD:R_0805_2012Metric_Pad1.20x1.40mm_HandSolder | Resistor | (Generic) | (Generic) | (Generic) |  |  | 0805
04-Batt-Prot | R10 |  | 330 |  |  |  | Resistor_SMD:R_0805_2012Metric_Pad1.20x1.40mm_HandSolder | Resistor | (Generic) | (Generic) | (Generic) |  |  | 0805
04-Batt-Prot | R11 |  | 2.2K |  |  |  | Resistor_SMD:R_0805_2012Metric_Pad1.20x1.40mm_HandSolder | Resistor | (Generic) | (Generic) | (Generic) |  |  | 0805
04-Batt-Prot | R12,R13 |  | 5.1M |  |  |  | Resistor_SMD:R_0805_2012Metric_Pad1.20x1.40mm_HandSolder | Resistor | (Generic) | (Generic) | (Generic) |  |  | 0805
02-DCDC,07-RTC | R15,R43 |  | 100K |  |  |  | Resistor_SMD:R_0805_2012Metric_Pad1.20x1.40mm_HandSolder | Resistor | (Generic) | (Generic) | (Generic) |  |  | 0805
02-DCDC | R16 |  | 200K |  |  |  | Resistor_SMD:R_0805_2012Metric_Pad1.20x1.40mm_HandSolder | Resistor | (Generic) | (Generic) | (Generic) |  |  | 0805
02-DCDC | R17 |  | 44.2K |  |  |  | Resistor_SMD:R_0805_2012Metric_Pad1.20x1.40mm_HandSolder | Resistor | (Generic) | (Generic) | (Generic) |  |  | 0805
06-MCU-IO | R20,R22 |  | 200 |  |  |  | Resistor_SMD:R_0805_2012Metric_Pad1.20x1.40mm_HandSolder | Resistor | (Generic) | (Generic) | (Generic) |  |  | 0805
06-MCU-IO | R27,R29 |  | 27 |  |  |  | Resistor_SMD:R_0805_2012Metric_Pad1.20x1.40mm_HandSolder | Resistor | (Generic) | (Generic) | (Generic) |  |  | 0805
05-MCU-XTAL-FLASH | R30,R31 |  | 100 |  |  |  | Resistor_SMD:R_0805_2012Metric_Pad1.20x1.40mm_HandSolder | Resistor | (Generic) | (Generic) | (Generic) |  |  | 0805
05-MCU-XTAL-FLASH | R33 |  | 1 |  |  |  | Resistor_SMD:R_0805_2012Metric_Pad1.20x1.40mm_HandSolder | Resistor | (Generic) | (Generic) | (Generic) |  |  | 0805
06-MCU-IO,07-RTC | R37,R42 |  | 470 |  |  |  | Resistor_SMD:R_0805_2012Metric_Pad1.20x1.40mm_HandSolder | Resistor | (Generic) | (Generic) | (Generic) |  |  | 0805

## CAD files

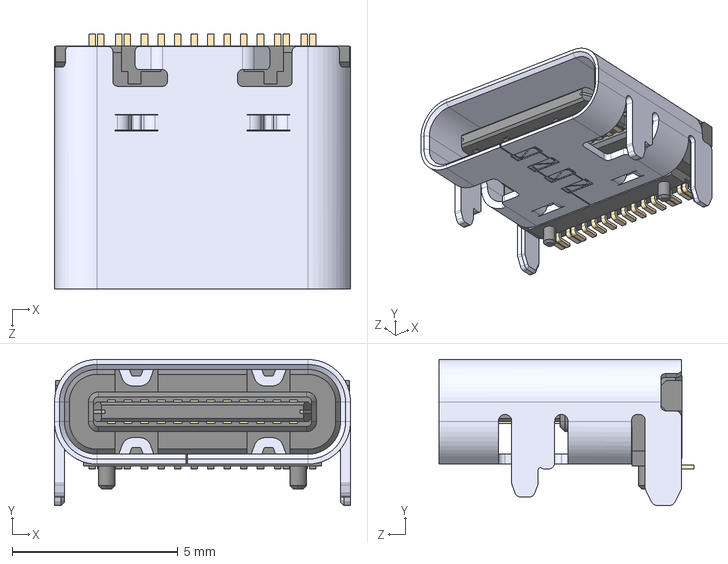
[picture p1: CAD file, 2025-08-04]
kicad/Project_Libraries/3dmodels/USB4105-GF-A.step
8.94 x 4.41 x 7.71 mm

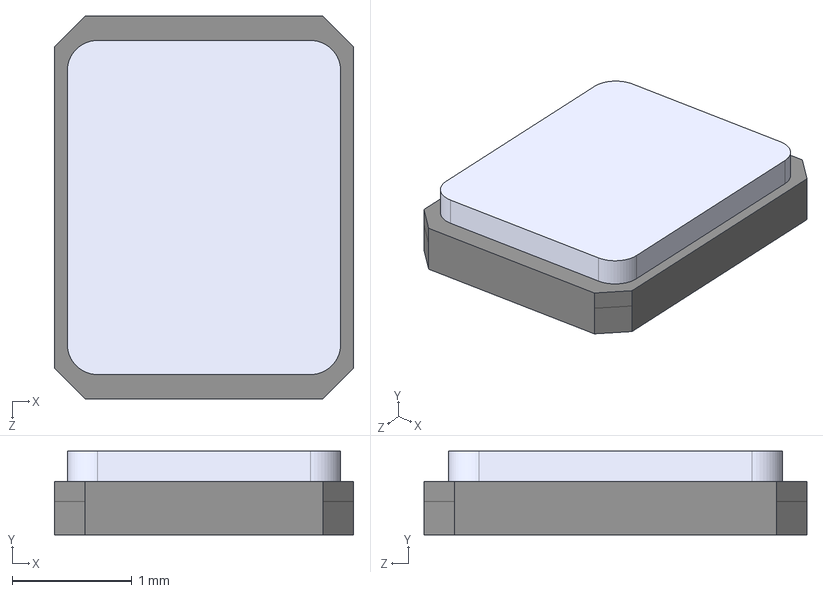
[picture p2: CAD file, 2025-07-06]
kicad/Project_Libraries/imports_source/ABM8_272_T3/ABM8-272-T3.step
2.50 x 0.7 x 3.20 mm

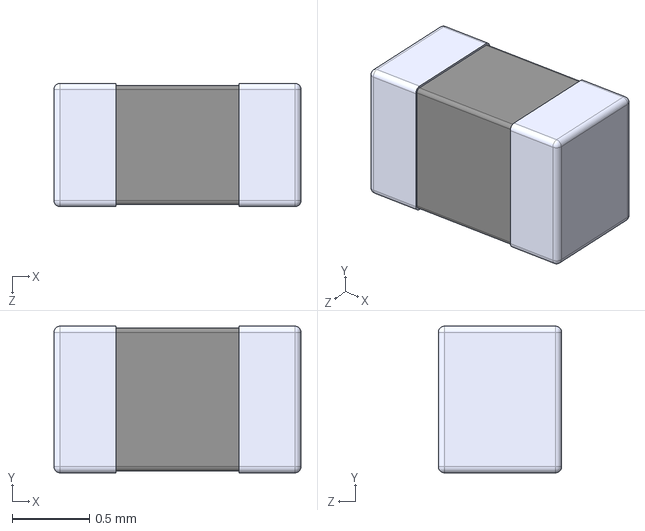
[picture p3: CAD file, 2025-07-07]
kicad/Project_Libraries/imports_source/BLM18PG221SN1D/BLM18PG221SN1D.step
1.60 x 0.95 x 0.8 mm

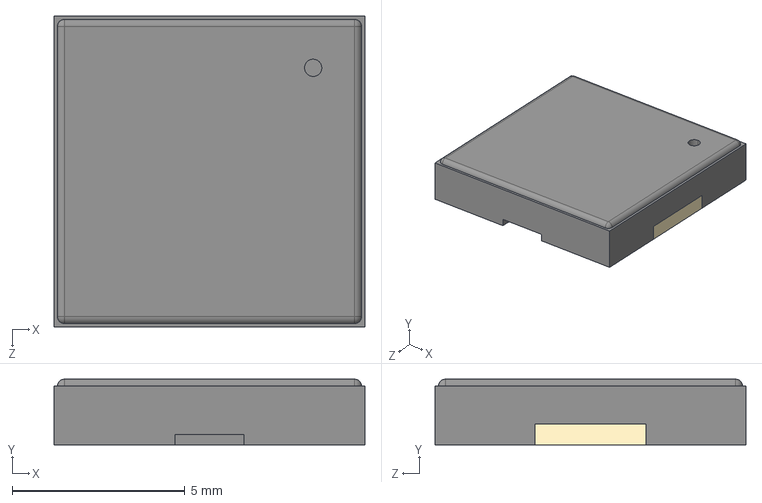
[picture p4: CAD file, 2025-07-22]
kicad/Project_Libraries/imports_source/PKMCS0909E4000_R1/PKMCS0909E4000-R1.step
9.00 x 1.90 x 9.00 mm

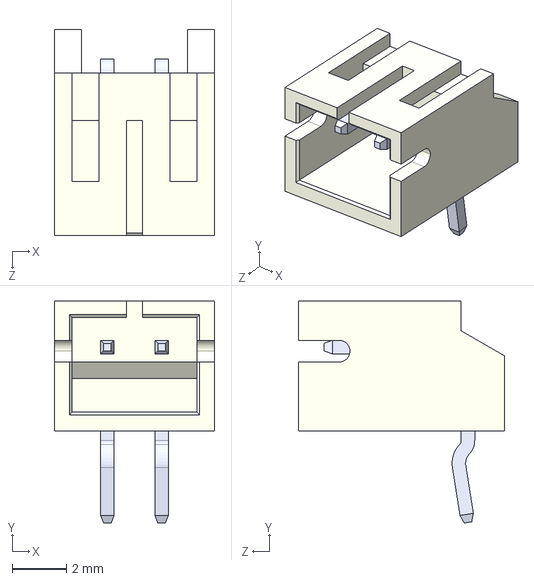
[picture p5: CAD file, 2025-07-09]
kicad/Project_Libraries/imports_source/S2B-PH-K-S_LF__SN_/S2B-PH-K-S_LF__SN_.step
5.90 x 8.18 x 7.60 mm

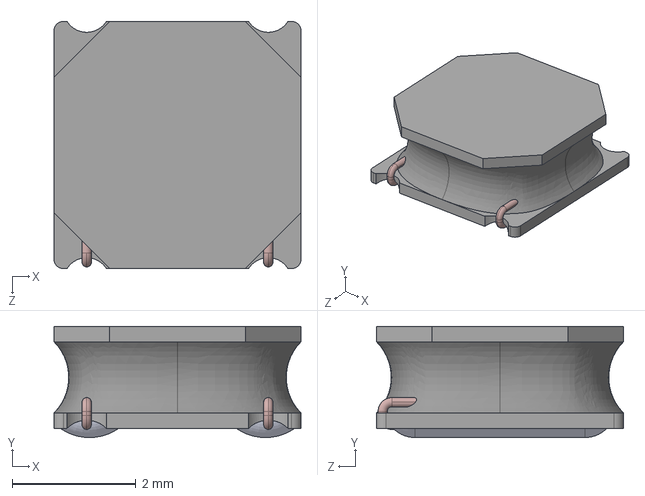
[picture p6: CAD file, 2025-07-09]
kicad/Project_Libraries/imports_source/SDER041H_2R2MS/SDER041H-2R2MS.step
4.00 x 1.80 x 4.00 mm

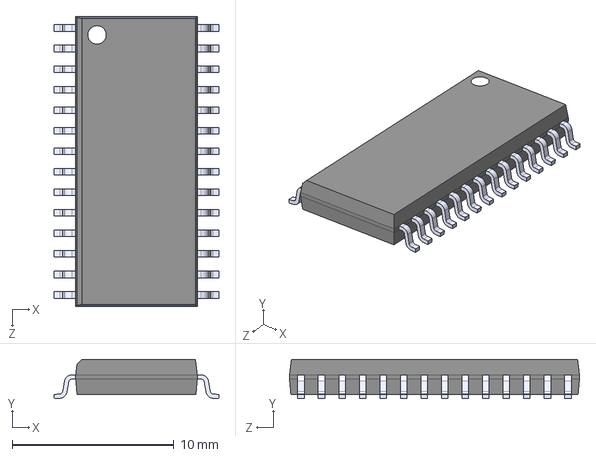
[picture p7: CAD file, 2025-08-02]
kicad/Project_Libraries/imports_source/TM1638/TM1638.step
10.2 x 2.44 x 17.9 mm

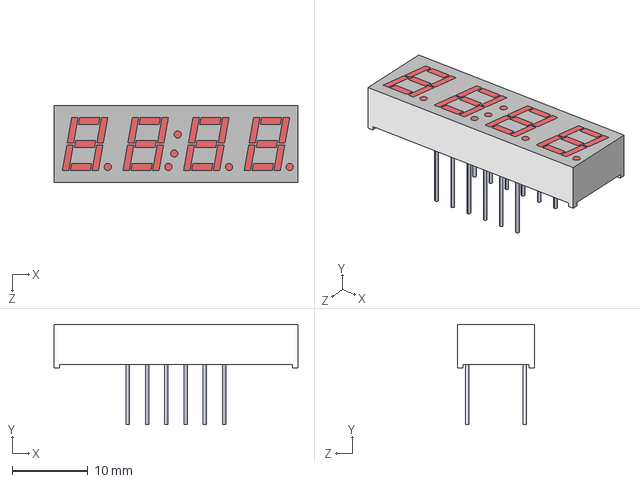
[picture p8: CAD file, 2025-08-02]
kicad/Project_Libraries/3dmodels/LDQ-M284RI--3DModel-STEP-510211.STEP
32.2 x 13.2 x 10.2 mm

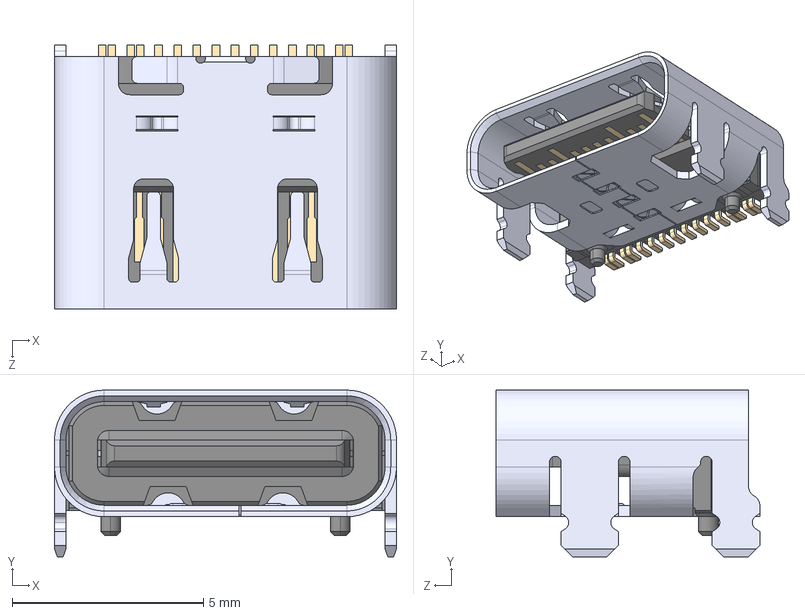
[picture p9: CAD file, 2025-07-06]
kicad/Project_Libraries/3dmodels/DX07S016JA1R1500--3DModel-STEP-1.STEP
8.94 x 4.36 x 6.90 mm

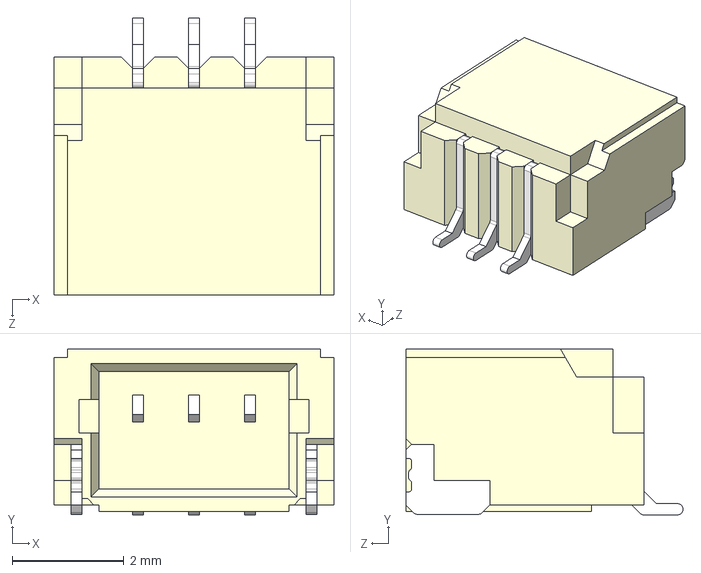
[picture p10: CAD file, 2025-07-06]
kicad/Project_Libraries/3dmodels/SM03B-SRSS-TB(LF)(SN)--3DModel-STEP-56544.STEP
5.00 x 2.96 x 4.95 mm

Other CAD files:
kicad/Project_Libraries/imports_source/BQ29700DSER/BQ29700DSER.step

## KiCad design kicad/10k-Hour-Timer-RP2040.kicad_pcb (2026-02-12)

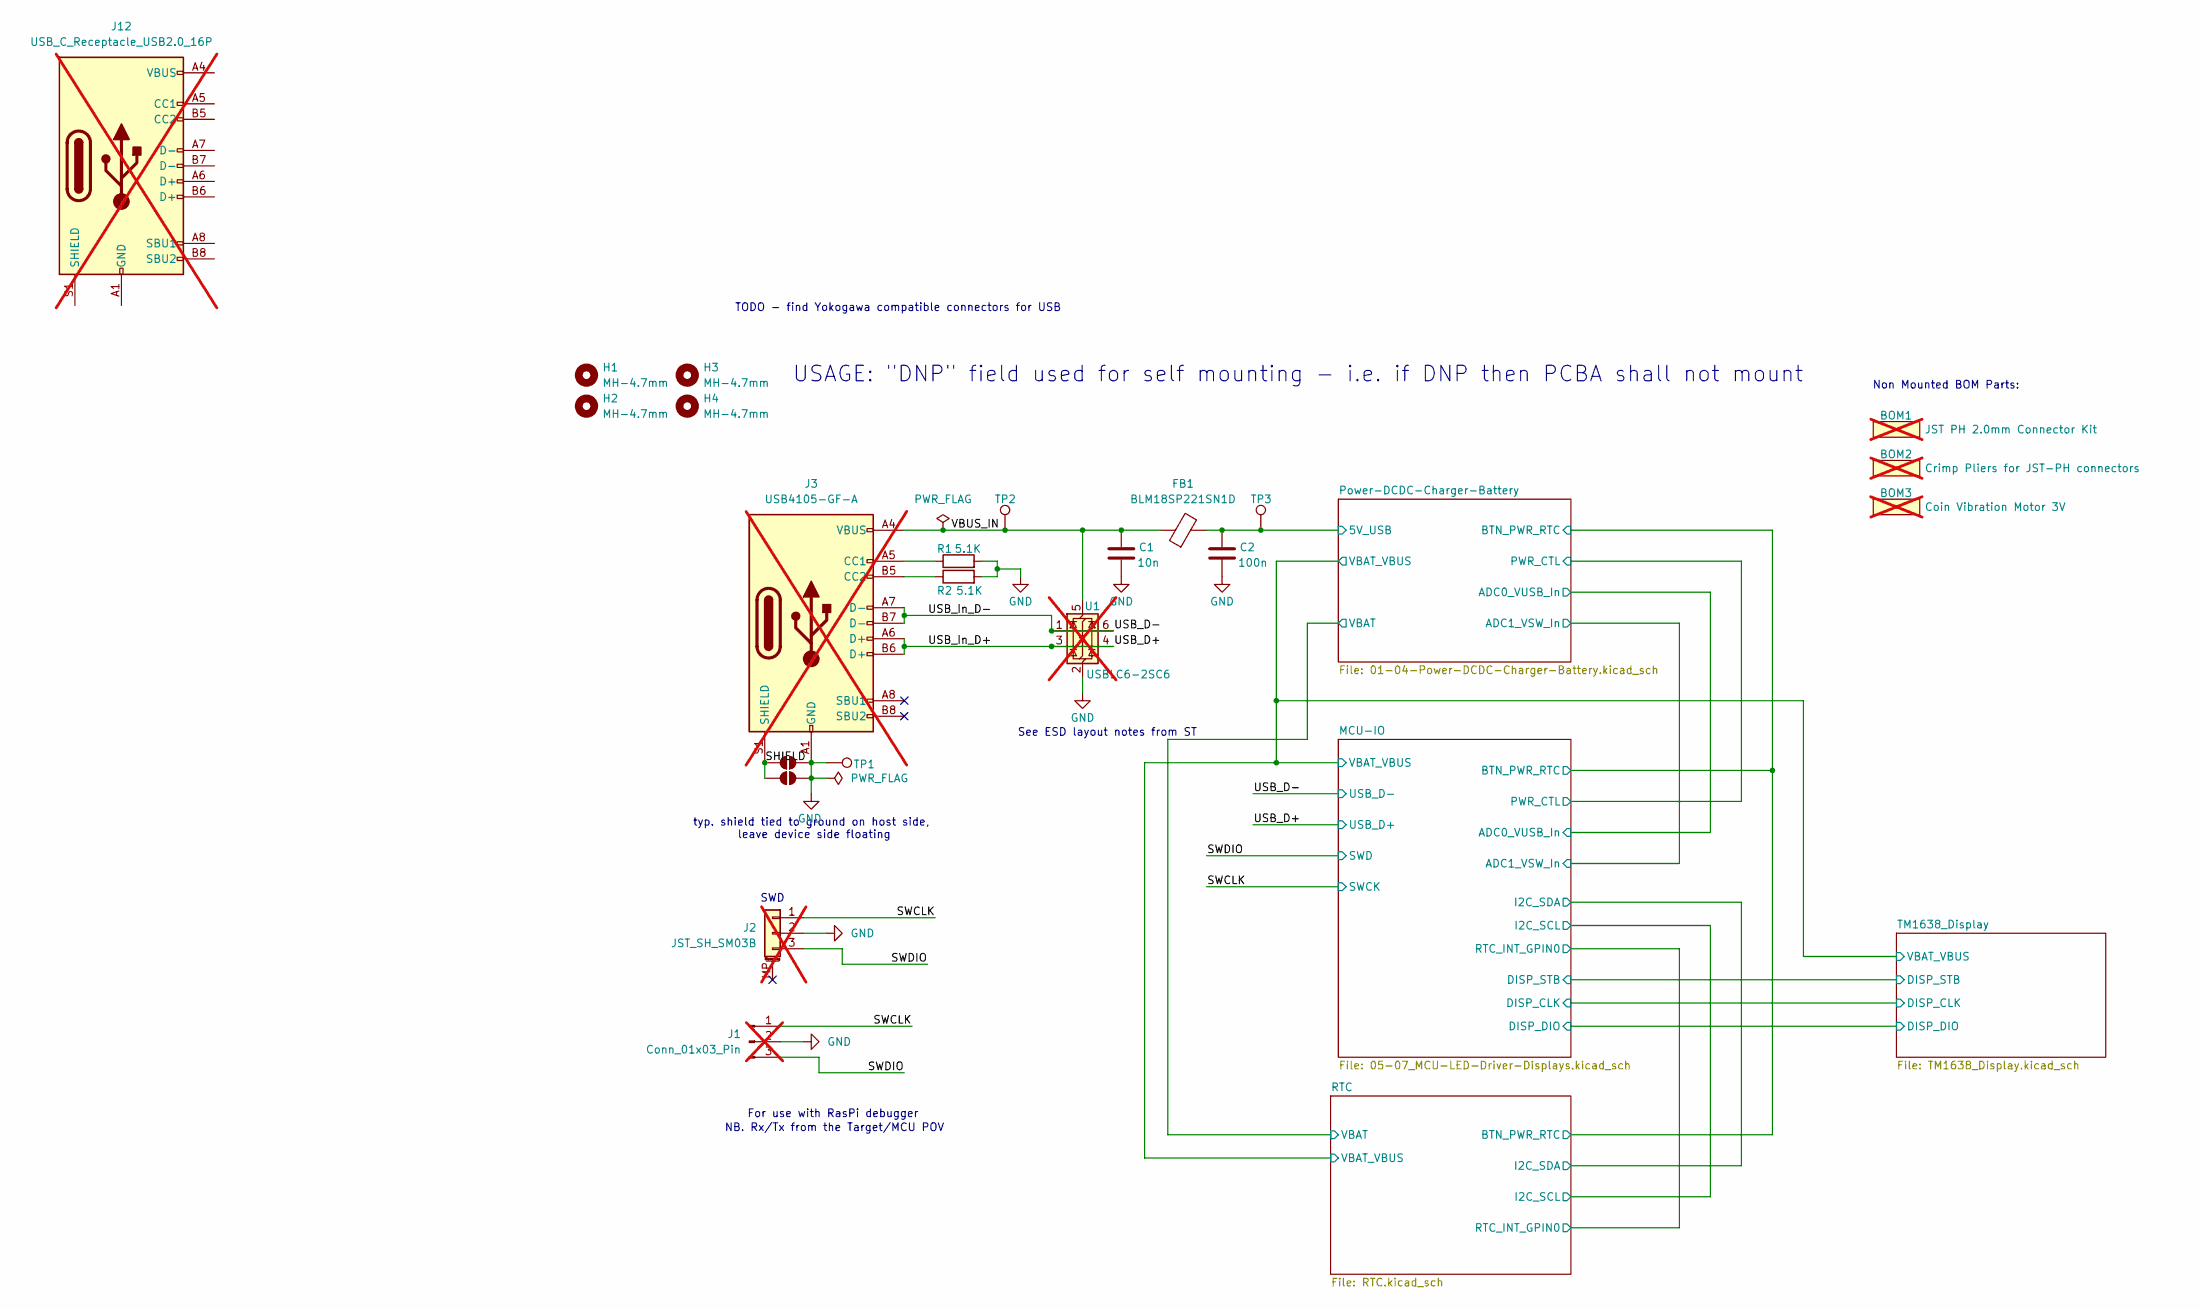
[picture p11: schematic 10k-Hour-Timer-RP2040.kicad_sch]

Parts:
BOM1: JST PH 2.0mm Connector Kit; not fitted
BOM2: Crimp Pliers for JST-PH connectors; MPN PA-09; not fitted
BOM3: Coin Vibration Motor 3V; MPN LCM0720A3134F; not fitted
C1: 10n; C_0603_1608Metric_Pad1.08x0.95mm_HandSolder; MPN (Generic)
C2: 100n; C_0603_1608Metric_Pad1.08x0.95mm_HandSolder; MPN (Generic)
FB1: BLM18SP221SN1D; BLM18SP221SN1D_BEADC1608X95N; MPN BLM18SP221SN1D
H1, H2, H3, H4: MH-4.7mm; MountingHole_4.7mm; MPN 8834
J1: Conn_01x03_Pin; PinHeader_1x03_P2.54mm_Vertical; MPN (Embedded); not fitted
J2: JST_SH_SM03B; JST_SH_SM03B-SRSS-TB_1x03-1MP_P1.00mm_Horizontal; MPN SM03B-SRSS-TB(LF)(SN); not fitted
J3: USB4105-GF-A; GCT_USB4105-GF-A; MPN USB4105-GF-A; not fitted
J12: USB_C_Receptacle_USB2.0_16P; USB_C_Receptacle_JAE_DX07S016JA1R1500; MPN DX07S016JA1R1500; not fitted
JP1, JP24: SolderJumper_2_Open; SolderJumper-2_P1.3mm_Open_RoundedPad1.0x1.5mm; MPN (Embedded)
R1, R2: 5.1K; R_0805_2012Metric_Pad1.20x1.40mm_HandSolder; MPN (Generic)
TP1: GND; TestPoint_THTPad_D2.0mm_Drill1.0mm; MPN (Embedded)
TP2: VBUS_IN; TestPoint_THTPad_D2.0mm_Drill1.0mm; MPN (Embedded)
TP3: VBUS; TestPoint_THTPad_D2.0mm_Drill1.0mm; MPN (Embedded)
U1: USBLC6-2SC6; SOT-23-6; MPN USBLC6-2SC6; not fitted

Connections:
/MCU-IO/ADC0_VUSB_In: C2.1, FB1.2, TP3.1; also elsewhere on the board
/SHIELD: J3.S1 (SHIELD), JP1.1 (A), JP24.1 (A)
/SWCLK: J1.1, J2.1; also elsewhere on the board
/SWDIO: J1.3, J2.3; also elsewhere on the board
/USB_D+: J3.A6 (D+), J3.B6 (D+), U1.3 (I/O2), U1.4 (I/O2); also elsewhere on the board
/USB_D-: J3.A7 (D-), J3.B7 (D-), U1.1 (I/O1), U1.6 (I/O1); also elsewhere on the board
/VBUS_IN: C1.1, FB1.1, J3.A4 (VBUS), J3.A9 (VBUS), J3.B4 (VBUS), J3.B9 (VBUS), TP2.1, U1.5 (VBUS)
GND: C1.2, C2.2, J1.2, J2.2, J3.A1 (GND), J3.A12 (GND), J3.B1 (GND), J3.B12 (GND), JP1.2 (B), JP24.2 (B), R1.2, R2.2, TP1.1, U1.2 (GND); also elsewhere on the board
unnamed: J3.A5 (CC1), R1.1
unnamed: J3.B5 (CC2), R2.1
unnamed: J12.A1 (GND), J12.A12 (GND), J12.B1 (GND), J12.B12 (GND)
unnamed: J12.A4 (VBUS), J12.A9 (VBUS), J12.B4 (VBUS), J12.B9 (VBUS)

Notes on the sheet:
For use with RasPi debugger
typ. shield tied to ground on host side, leave device side floating
See ESD layout notes from ST
Non Mounted BOM Parts:
TODO - find Yokogawa compatible connectors for USB
USAGE: "DNP" field used for self mounting - i.e. if DNP then PCBA shall not mount
SWD
NB. Rx/Tx from the Target/MCU POV

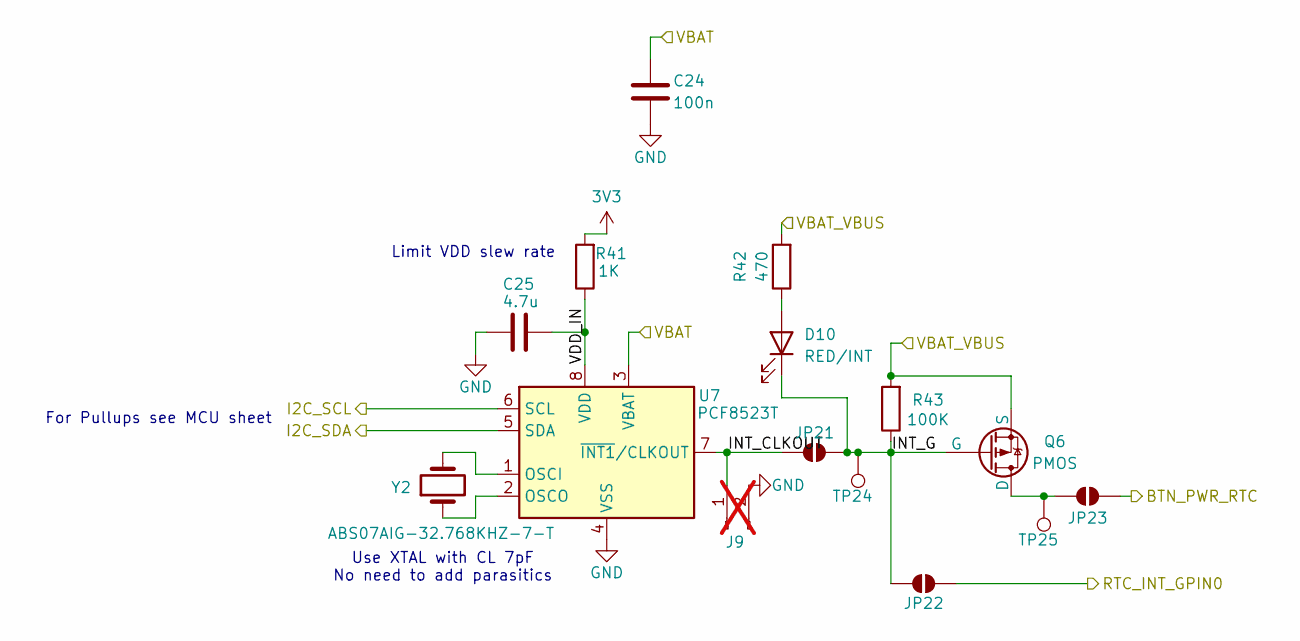
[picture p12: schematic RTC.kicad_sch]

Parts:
C24: 100n; C_0603_1608Metric_Pad1.08x0.95mm_HandSolder; MPN (Generic)
C25: 4.7u; C_0603_1608Metric_Pad1.08x0.95mm_HandSolder; MPN (Generic)
D10: RED/INT; LED_0805_2012Metric; MPN NCD0805R1
J9: Conn_01x02_Pin; PinHeader_1x02_P2.54mm_Vertical; not fitted
JP21, JP22, JP23: SolderJumper_2_Open; SolderJumper-2_P1.3mm_Open_RoundedPad1.0x1.5mm; MPN (Embedded)
Q6: PMOS; SOT-23; MPN SI2301CDS-T1-GE3
R41: 1K; R_0805_2012Metric_Pad1.20x1.40mm_HandSolder; MPN (Generic)
R42: 470; R_0805_2012Metric_Pad1.20x1.40mm_HandSolder; MPN (Generic)
R43: 100K; R_0805_2012Metric_Pad1.20x1.40mm_HandSolder; MPN (Generic)
TP24: INT_G; TestPoint_THTPad_D2.0mm_Drill1.0mm; MPN (Embedded)
TP25: INT_D; TestPoint_THTPad_D2.0mm_Drill1.0mm; MPN (Embedded)
U7: PCF8523T; SOIC-8_3.9x4.9mm_P1.27mm; MPN PCF8523T/1,118
Y2: ABS07AIG-32.768KHZ-7-T; Crystal_SMD_3215-2Pin_3.2x1.5mm; MPN ABS07AIG-32.768KHZ-7-T

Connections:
3V3: R41.2; also elsewhere on the board
/MCU-IO/I2C_SCL: U7.6 (SCL); also elsewhere on the board
/MCU-IO/I2C_SDA: U7.5 (SDA); also elsewhere on the board
/MCU-IO/IO_Gate: JP23.2 (B); also elsewhere on the board
/MCU-IO/RTC_INT_GPIN0: JP22.1 (A); also elsewhere on the board
/MCU-IO/VBAT_VBUS: Q6.3 (S), R42.2, R43.2; also elsewhere on the board
/Power-DCDC-Charger-Battery/VBAT: C24.1, U7.3 (VBAT); also elsewhere on the board
/RTC/INT_CLKOUT: J9.1, JP21.1 (A), U7.7 (~INT1/CLKOUT)
/RTC/INT_G: D10.1 (K), JP21.2 (B), JP22.2 (B), Q6.2 (G), R43.1, TP24.1
/RTC/VDD_IN: C25.1, R41.1, U7.8 (VDD)
GND: C24.2, C25.2, J9.2, U7.4 (VSS); also elsewhere on the board
unnamed: D10.2 (A), R42.1
unnamed: JP23.1 (A), Q6.1 (D), TP25.1
unnamed: U7.1 (OSCI), Y2.2
unnamed: U7.2 (OSCO), Y2.1

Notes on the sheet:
For Pullups see MCU sheet
Limit VDD slew rate
Use XTAL with CL 7pF No need to add parasitics

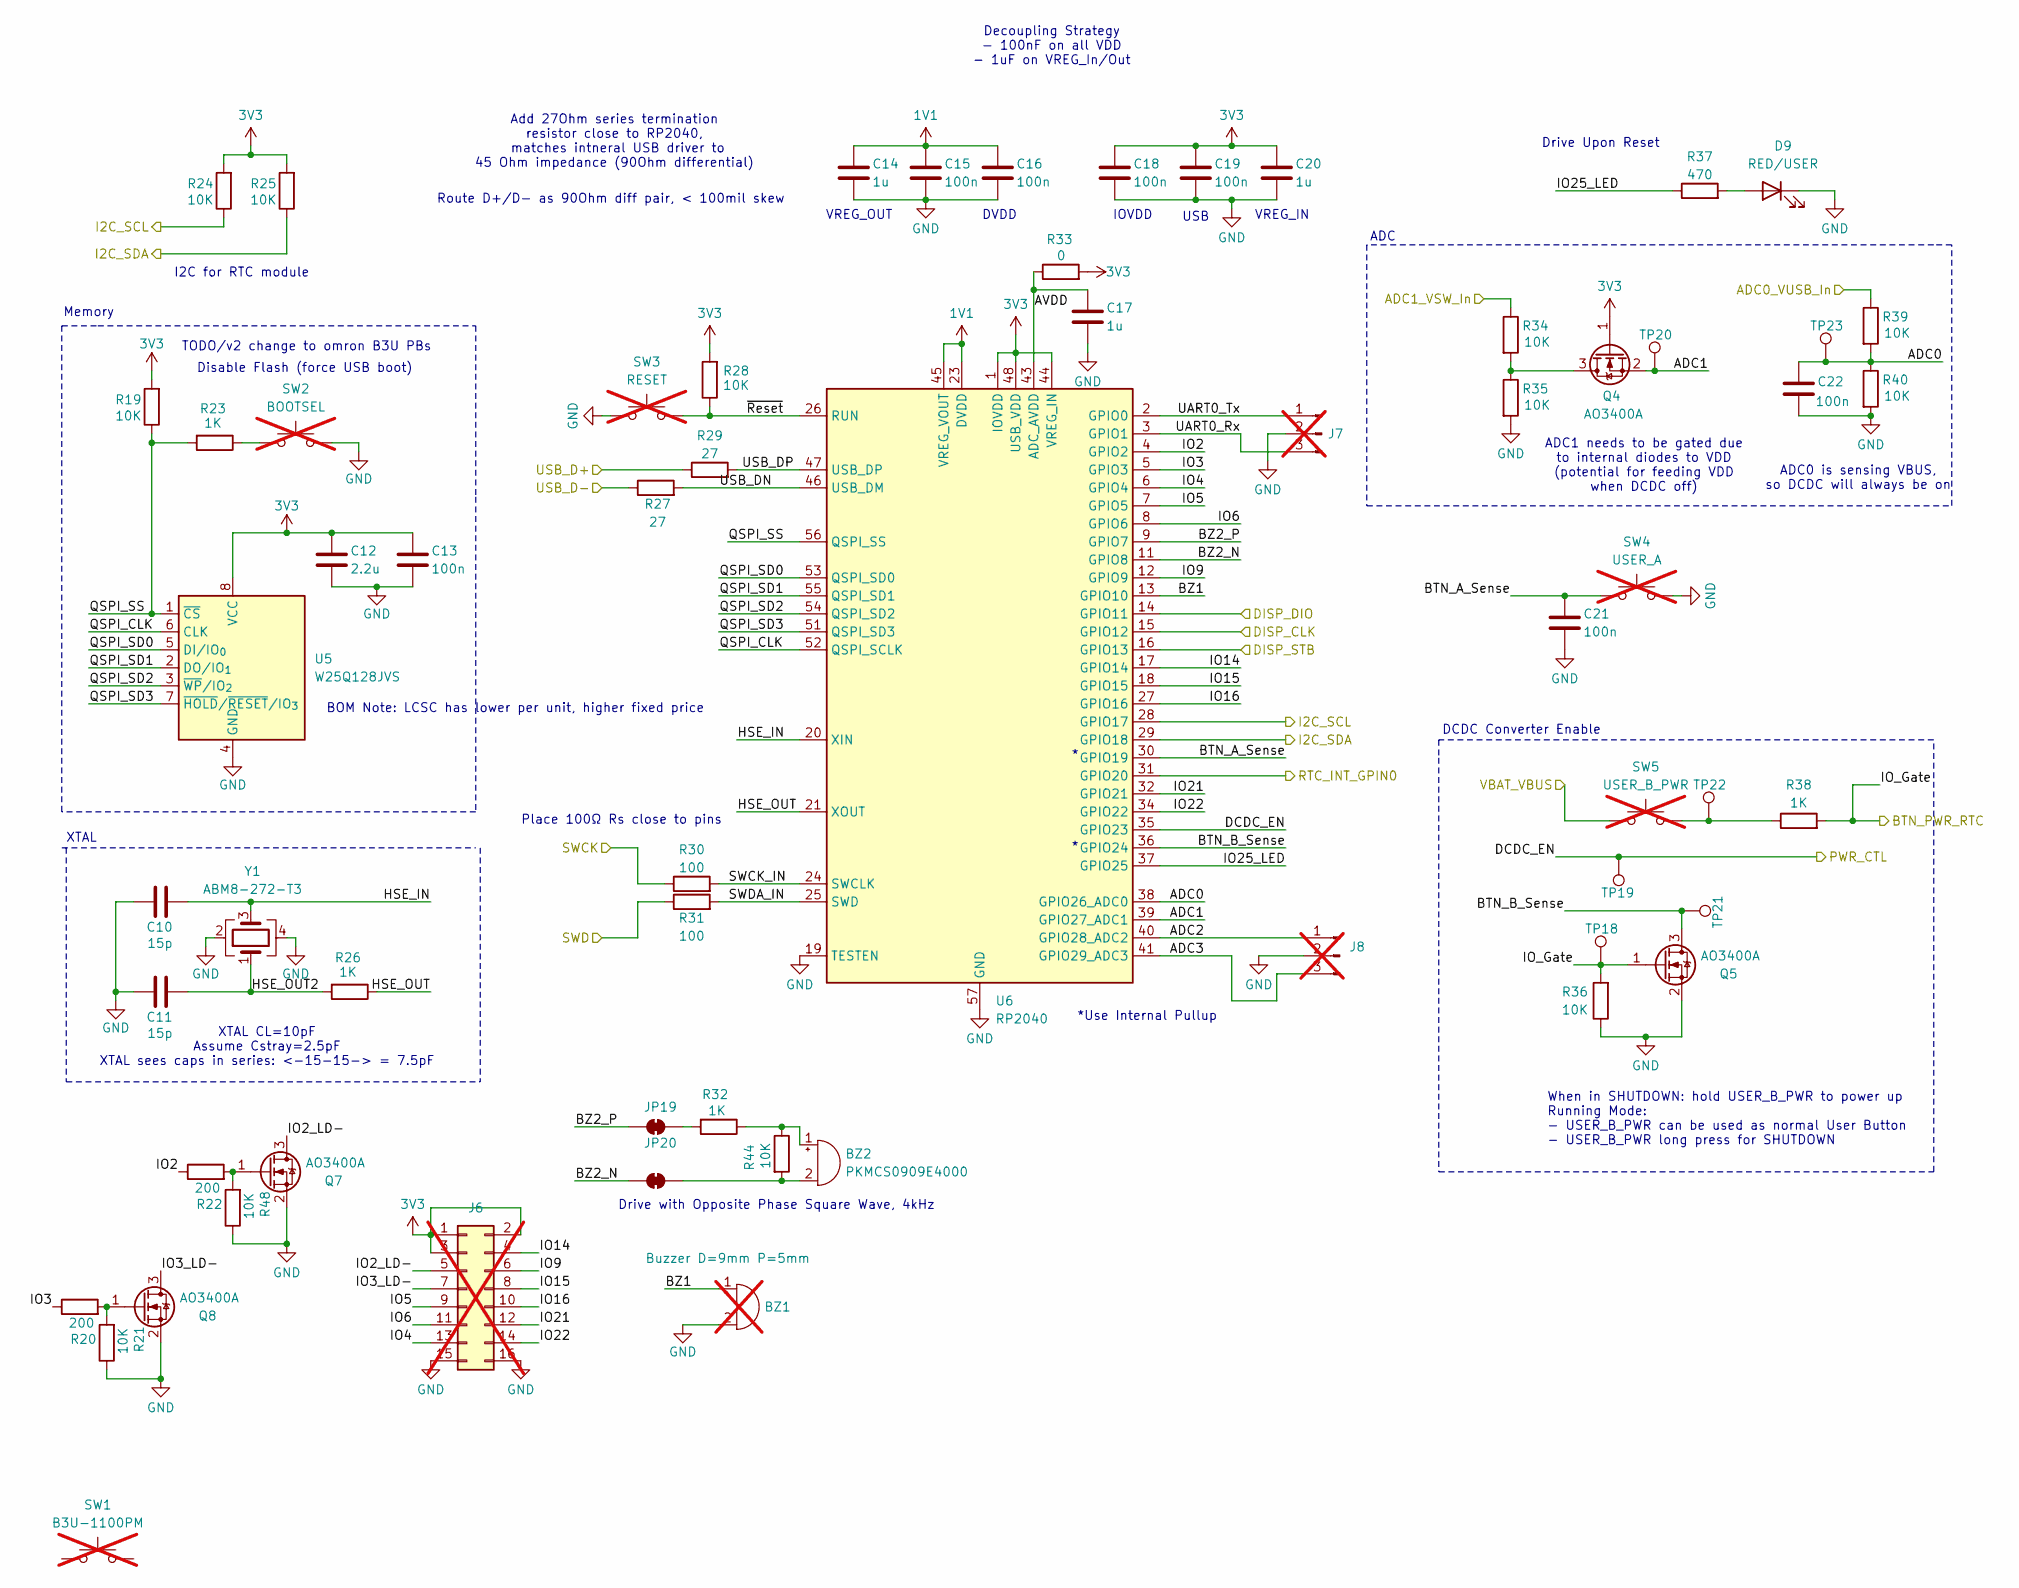
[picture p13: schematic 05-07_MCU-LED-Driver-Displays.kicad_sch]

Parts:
BZ1: Buzzer D=9mm P=5mm; Buzzer-TH_D9.6_P5; MPN HNB09A05; not fitted
BZ2: PKMCS0909E4000; Buzzer_SPKR_PKMCS0909E4000-R1; MPN PKMCS0909E4000-R1
C10, C11: 15p; C_0603_1608Metric_Pad1.08x0.95mm_HandSolder; MPN (Generic)
C12: 2.2u; C_0603_1608Metric_Pad1.08x0.95mm_HandSolder; MPN (Generic)
C13, C15, C16, C18, C19, C21, C22: 100n; C_0603_1608Metric_Pad1.08x0.95mm_HandSolder; MPN (Generic)
C14, C17, C20: 1u; C_0603_1608Metric_Pad1.08x0.95mm_HandSolder; MPN (Generic)
D9: RED/USER; LED_0805_2012Metric; MPN NCD0805R1
J6: Conn_02x08_Counter_Clockwise; PinHeader_2x08_P2.54mm_Vertical; not fitted
J7, J8: Conn_01x03_Pin; PinHeader_1x03_P2.54mm_Vertical; MPN (Embedded); not fitted
JP19, JP20: SolderJumper_2_Bridged; SolderJumper-2_P1.3mm_Bridged_RoundedPad1.0x1.5mm; MPN (Embedded)
Q4, Q5, Q7, Q8: AO3400A; SOT-23; MPN AO3400A
R19, R21, R24, R25, R28, R34, R35, R36, R39, R40, R44, R48: 10K; R_0805_2012Metric_Pad1.20x1.40mm_HandSolder; MPN (Generic)
R20, R22: 200; R_0805_2012Metric_Pad1.20x1.40mm_HandSolder; MPN (Generic)
R23, R26, R32, R38: 1K; R_0805_2012Metric_Pad1.20x1.40mm_HandSolder; MPN (Generic)
R27, R29: 27; R_0805_2012Metric_Pad1.20x1.40mm_HandSolder; MPN (Generic)
R30, R31: 100; R_0805_2012Metric_Pad1.20x1.40mm_HandSolder; MPN (Generic)
R33: 0; R_0805_2012Metric_Pad1.20x1.40mm_HandSolder; MPN (Generic)
R37: 470; R_0805_2012Metric_Pad1.20x1.40mm_HandSolder; MPN (Generic)
SW1: B3U-1100PM; SW_SPST_B3U-1100P; MPN B3U-1100PM; not fitted
SW2: BOOTSEL; SW_PUSH_6mm; MPN (Generic)/1825910-6; not fitted
SW3: RESET; SW_PUSH_6mm; MPN (Generic)/1825910-6; not fitted
SW4: USER_A; SW_PUSH_6mm; MPN (Generic)/1825910-6; not fitted
SW5: USER_B_PWR; SW_PUSH_6mm; MPN (Generic)/1825910-6; not fitted
TP18: IOGate; TestPoint_THTPad_D2.0mm_Drill1.0mm; MPN (Embedded)
TP19: DCDC_EN; TestPoint_THTPad_D2.0mm_Drill1.0mm; MPN (Embedded)
TP20: ADC1; TestPoint_THTPad_D2.0mm_Drill1.0mm; MPN (Embedded)
TP21: BTN_B; TestPoint_THTPad_D2.0mm_Drill1.0mm; MPN (Embedded)
TP22: BTN_B_IN; TestPoint_THTPad_D2.0mm_Drill1.0mm; MPN (Embedded)
TP23: ADC0; TestPoint_THTPad_D2.0mm_Drill1.0mm; MPN (Embedded)
U5: W25Q128JVS; SOIC-8_5.3x5.3mm_P1.27mm; MPN W25Q128JVSIQ
U6: RP2040; QFN-56-1EP_7x7mm_P0.4mm_EP3.2x3.2mm; MPN SC0914(13)
Y1: ABM8-272-T3; XTAL_ABM8-272-T3; MPN ABM8-272-T3

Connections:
1V1: C14.1, C15.1, C16.1, U6.23 (DVDD), U6.45 (VREG_VOUT), U6.50 (DVDD)
3V3: C12.1, C13.1, C18.1, C19.1, C20.1, J6.1, J6.2, J6.3, Q4.1 (G), R19.2, R24.2, R25.2, R28.2, R33.2, U5.8 (VCC), U6.1 (IOVDD), U6.10 (IOVDD), U6.22 (IOVDD), U6.33 (IOVDD), U6.42 (IOVDD), U6.44 (VREG_IN), U6.48 (USB_VDD), U6.49 (IOVDD); also elsewhere on the board
/MCU-IO/ADC0: C22.1, R39.2, R40.1, TP23.1, U6.38 (GPIO26_ADC0)
/MCU-IO/ADC0_VUSB_In: R39.1; also elsewhere on the board
/MCU-IO/ADC1: Q4.2 (S), TP20.1, U6.39 (GPIO27_ADC1)
/MCU-IO/ADC1_VSW_In: R34.1; also elsewhere on the board
/MCU-IO/ADC2: J8.1, U6.40 (GPIO28_ADC2)
/MCU-IO/ADC3: J8.3, U6.41 (GPIO29_ADC3)
/MCU-IO/AVDD: C17.1, R33.1, U6.43 (ADC_AVDD)
/MCU-IO/BTN_A_Sense: C21.1, SW4.1, U6.30 (GPIO19)
/MCU-IO/BTN_B_Sense: Q5.3 (D), TP21.1, U6.36 (GPIO24)
/MCU-IO/BZ1: BZ1.1 (+), U6.13 (GPIO10)
/MCU-IO/BZ2_N: JP20.2 (B), U6.11 (GPIO8)
/MCU-IO/BZ2_P: JP19.2 (B), U6.9 (GPIO7)
/MCU-IO/DCDC_EN: TP19.1, U6.35 (GPIO23); also elsewhere on the board
/MCU-IO/DISP_CLK: U6.15 (GPIO12); also elsewhere on the board
/MCU-IO/DISP_DIO: U6.14 (GPIO11); also elsewhere on the board
/MCU-IO/DISP_STB: U6.16 (GPIO13); also elsewhere on the board
/MCU-IO/HSE_IN: C10.2, U6.20 (XIN), Y1.3
/MCU-IO/HSE_OUT: R26.1, U6.21 (XOUT)
/MCU-IO/HSE_OUT2: C11.2, R26.2, Y1.1
/MCU-IO/I2C_SCL: R24.1, U6.28 (GPIO17); also elsewhere on the board
/MCU-IO/I2C_SDA: R25.1, U6.29 (GPIO18); also elsewhere on the board
/MCU-IO/IO2: R22.1, U6.4 (GPIO2)
/MCU-IO/IO2_LD-: J6.5, Q7.3 (D)
/MCU-IO/IO3: R20.1, U6.5 (GPIO3)
/MCU-IO/IO3_LD-: J6.7, Q8.3 (D)
/MCU-IO/IO4: J6.13, U6.6 (GPIO4)
/MCU-IO/IO5: J6.9, U6.7 (GPIO5)
/MCU-IO/IO6: J6.11, U6.8 (GPIO6)
/MCU-IO/IO9: J6.6, U6.12 (GPIO9)
/MCU-IO/IO14: J6.4, U6.17 (GPIO14)
/MCU-IO/IO15: J6.8, U6.18 (GPIO15)
/MCU-IO/IO16: J6.10, U6.27 (GPIO16)
/MCU-IO/IO21: J6.12, U6.32 (GPIO21)
/MCU-IO/IO22: J6.14, U6.34 (GPIO22)
/MCU-IO/IO25_LED: R37.1, U6.37 (GPIO25)
/MCU-IO/IO_Gate: Q5.1 (G), R36.2, R38.2, TP18.1; also elsewhere on the board
/MCU-IO/QSPI_CLK: U5.6 (CLK), U6.52 (QSPI_SCLK)
/MCU-IO/QSPI_SD0: U5.5 (DI/IO_{0}), U6.53 (QSPI_SD0)
/MCU-IO/QSPI_SD1: U5.2 (DO/IO_{1}), U6.55 (QSPI_SD1)
/MCU-IO/QSPI_SD2: U5.3 (~WP/IO_{2}), U6.54 (QSPI_SD2)
/MCU-IO/QSPI_SD3: U5.7 (~HOLD/~RESET/IO_{3}), U6.51 (QSPI_SD3)
/MCU-IO/QSPI_SS: R19.1, R23.2, U5.1 (~CS), U6.56 (QSPI_SS)
/MCU-IO/RTC_INT_GPIN0: U6.31 (GPIO20); also elsewhere on the board
/MCU-IO/SWCK_IN: R30.2, U6.24 (SWCLK)
/MCU-IO/SWDA_IN: R31.2, U6.25 (SWD)
/MCU-IO/UART0_Rx: J7.3, U6.3 (GPIO1)
/MCU-IO/UART0_Tx: J7.1, U6.2 (GPIO0)
/MCU-IO/USB_DN: R27.2, U6.46 (USB_DM)
/MCU-IO/USB_DP: R29.2, U6.47 (USB_DP)
/MCU-IO/VBAT_VBUS: SW5.1; also elsewhere on the board
/MCU-IO/~Reset: R28.1, SW3.2, U6.26 (RUN)
/SWCLK: R30.1; also elsewhere on the board
/SWDIO: R31.1; also elsewhere on the board
/USB_D+: R29.1; also elsewhere on the board
/USB_D-: R27.1; also elsewhere on the board
GND: BZ1.2 (-), C10.1, C11.1, C12.2, C13.2, C14.2, C15.2, C16.2, C17.2, C18.2, C19.2, C20.2, C21.2, C22.2, D9.1 (K), J6.15, J6.16, J7.2, J8.2, Q5.2 (S), Q7.2 (S), Q8.2 (S), R21.1, R35.2, R36.1, R40.2, R48.1, SW2.2, SW3.1, SW4.2, U5.4 (GND), U6.19 (TESTEN), U6.57 (GND), Y1.2, Y1.4; also elsewhere on the board
unnamed: BZ2.1 (+), R32.1, R44.1
unnamed: BZ2.2 (-), JP20.1 (A), R44.2
unnamed: D9.2 (A), R37.2
unnamed: JP19.1 (A), R32.2
unnamed: Q4.3 (D), R34.2, R35.1
unnamed: Q7.1 (G), R22.2, R48.2
unnamed: Q8.1 (G), R20.2, R21.2
unnamed: R23.1, SW2.1
unnamed: R38.1, SW5.2, TP22.1

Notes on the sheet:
Route D+/D- as 90Ohm diff pair, < 100mil skew
XTAL
TODO/v2 change to omron B3U PBs
XTAL CL=10pF Assume Cstray=2.5pF XTAL sees caps in series: <-15-15-> = 7.5pF
Disable Flash (force USB boot)
BOM Note: LCSC has lower per unit, higher fixed price
When in SHUTDOWN: hold USER_B_PWR to power up Running Mode: - USER_B_PWR can be used as normal User Button - USER_B_PWR long press for SHUTDOWN
I2C for RTC module
IOVDD
ADC0 is sensing VBUS, so DCDC will always be on
VREG_OUT
USB
Add 27Ohm series termination resistor close to RP2040, matches intneral USB driver to 45 Ohm impedance (90Ohm differential)
*Use Internal Pullup
Place 100Ω Rs close to pins
DCDC Converter Enable
Memory
Drive Upon Reset
Decoupling Strategy - 100nF on all VDD - 1uF on VREG_In/Out
Drive with Opposite Phase Square Wave, 4kHz
ADC
VREG_IN
DVDD
ADC1 needs to be gated due to internal diodes to VDD (potential for feeding VDD when DCDC off)

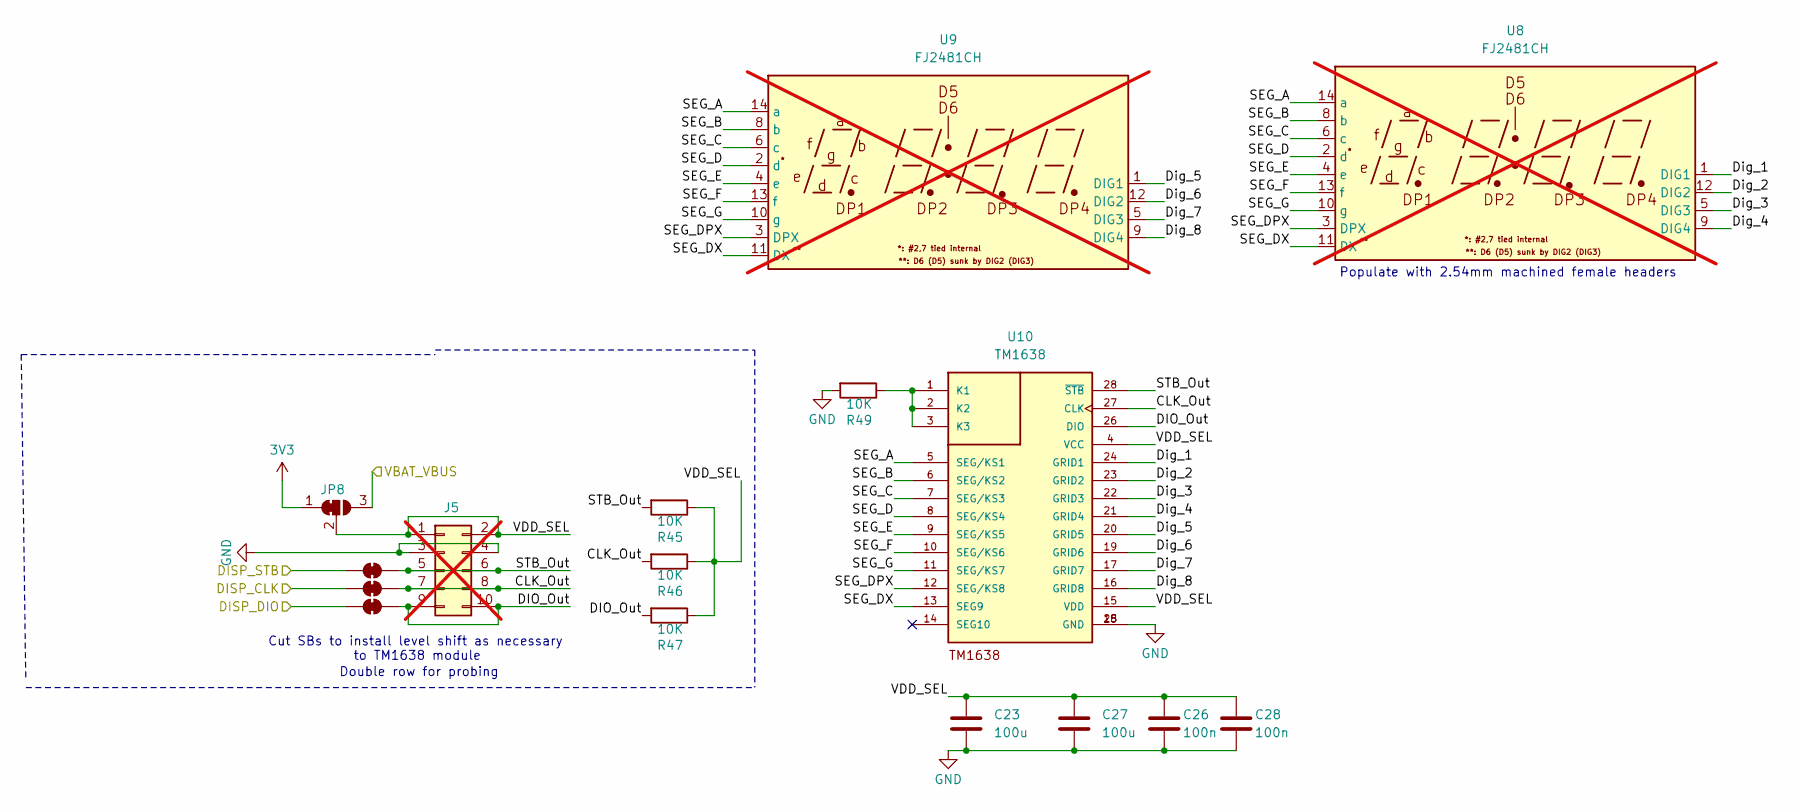
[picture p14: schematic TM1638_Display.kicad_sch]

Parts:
C23, C27: 100u; C_1206_3216Metric; MPN CL31A107MQHNNNE
C26, C28: 100n; C_0603_1608Metric_Pad1.08x0.95mm_HandSolder; MPN (Generic)
J5: Conn_02x05_Counter_Clockwise; PinHeader_2x05_P2.54mm_Vertical; not fitted
JP8: SolderJumper_3_Bridged12; SolderJumper-3_P1.3mm_Bridged12_RoundedPad1.0x1.5mm
JP16, JP17, JP18: SolderJumper_2_Bridged; SolderJumper-2_P1.3mm_Bridged_RoundedPad1.0x1.5mm; MPN (Embedded)
R45, R46, R47, R49: 10K; R_0805_2012Metric_Pad1.20x1.40mm_HandSolder; MPN (Generic)
U8, U9: FJ2481CH; 7-Seg-CC28-FJ2481CH; MPN FJ2481CH; not fitted
U10: TM1638; SOIC127P1041X265-28N; MPN TM1638

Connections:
3V3: JP8.1 (A); also elsewhere on the board
/MCU-IO/DISP_CLK: JP17.2 (B); also elsewhere on the board
/MCU-IO/DISP_DIO: JP18.2 (B); also elsewhere on the board
/MCU-IO/DISP_STB: JP16.2 (B); also elsewhere on the board
/MCU-IO/VBAT_VBUS: JP8.3 (B); also elsewhere on the board
/TM1638_Display/CLK_Out: J5.7, J5.8, JP17.1 (A), R46.2, U10.27 (CLK)
/TM1638_Display/DIO_Out: J5.9, J5.10, JP18.1 (A), R47.2, U10.26 (DIO)
/TM1638_Display/Dig_1: U8.1 (DIG1), U10.24 (GRID1)
/TM1638_Display/Dig_2: U8.12 (DIG2), U10.23 (GRID2)
/TM1638_Display/Dig_3: U8.5 (DIG3), U10.22 (GRID3)
/TM1638_Display/Dig_4: U8.9 (DIG4), U10.21 (GRID4)
/TM1638_Display/Dig_5: U9.1 (DIG1), U10.20 (GRID5)
/TM1638_Display/Dig_6: U9.12 (DIG2), U10.19 (GRID6)
/TM1638_Display/Dig_7: U9.5 (DIG3), U10.17 (GRID7)
/TM1638_Display/Dig_8: U9.9 (DIG4), U10.16 (GRID8)
/TM1638_Display/SEG_A: U8.14 (a), U9.14 (a), U10.5 (SEG/KS1)
/TM1638_Display/SEG_B: U8.8 (b), U9.8 (b), U10.6 (SEG/KS2)
/TM1638_Display/SEG_C: U8.6 (c), U9.6 (c), U10.7 (SEG/KS3)
/TM1638_Display/SEG_D: U8.2 (d), U8.7 (NA), U9.2 (d), U9.7 (NA), U10.8 (SEG/KS4)
/TM1638_Display/SEG_DPX: U8.3 (DPX), U9.3 (DPX), U10.12 (SEG/KS8)
/TM1638_Display/SEG_DX: U8.11 (DX), U9.11 (DX), U10.13 (SEG9)
/TM1638_Display/SEG_E: U8.4 (e), U9.4 (e), U10.9 (SEG/KS5)
/TM1638_Display/SEG_F: U8.13 (f), U9.13 (f), U10.10 (SEG/KS6)
/TM1638_Display/SEG_G: U8.10 (g), U9.10 (g), U10.11 (SEG/KS7)
/TM1638_Display/STB_Out: J5.5, J5.6, JP16.1 (A), R45.2, U10.28 (~STB)
/TM1638_Display/VDD_SEL: C23.1, C26.1, C27.1, C28.1, J5.1, J5.2, JP8.2 (C), R45.1, R46.1, R47.1, U10.4 (VCC), U10.15 (VDD)
GND: C23.2, C26.2, C27.2, C28.2, J5.3, J5.4, R49.2, U10.18 (GND), U10.25 (GND); also elsewhere on the board
unnamed: R49.1, U10.1 (K1), U10.2 (K2), U10.3 (K3)

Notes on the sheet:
to TM1638 module
Populate with 2.54mm machined female headers
Double row for probing
Cut SBs to install level shift as necessary

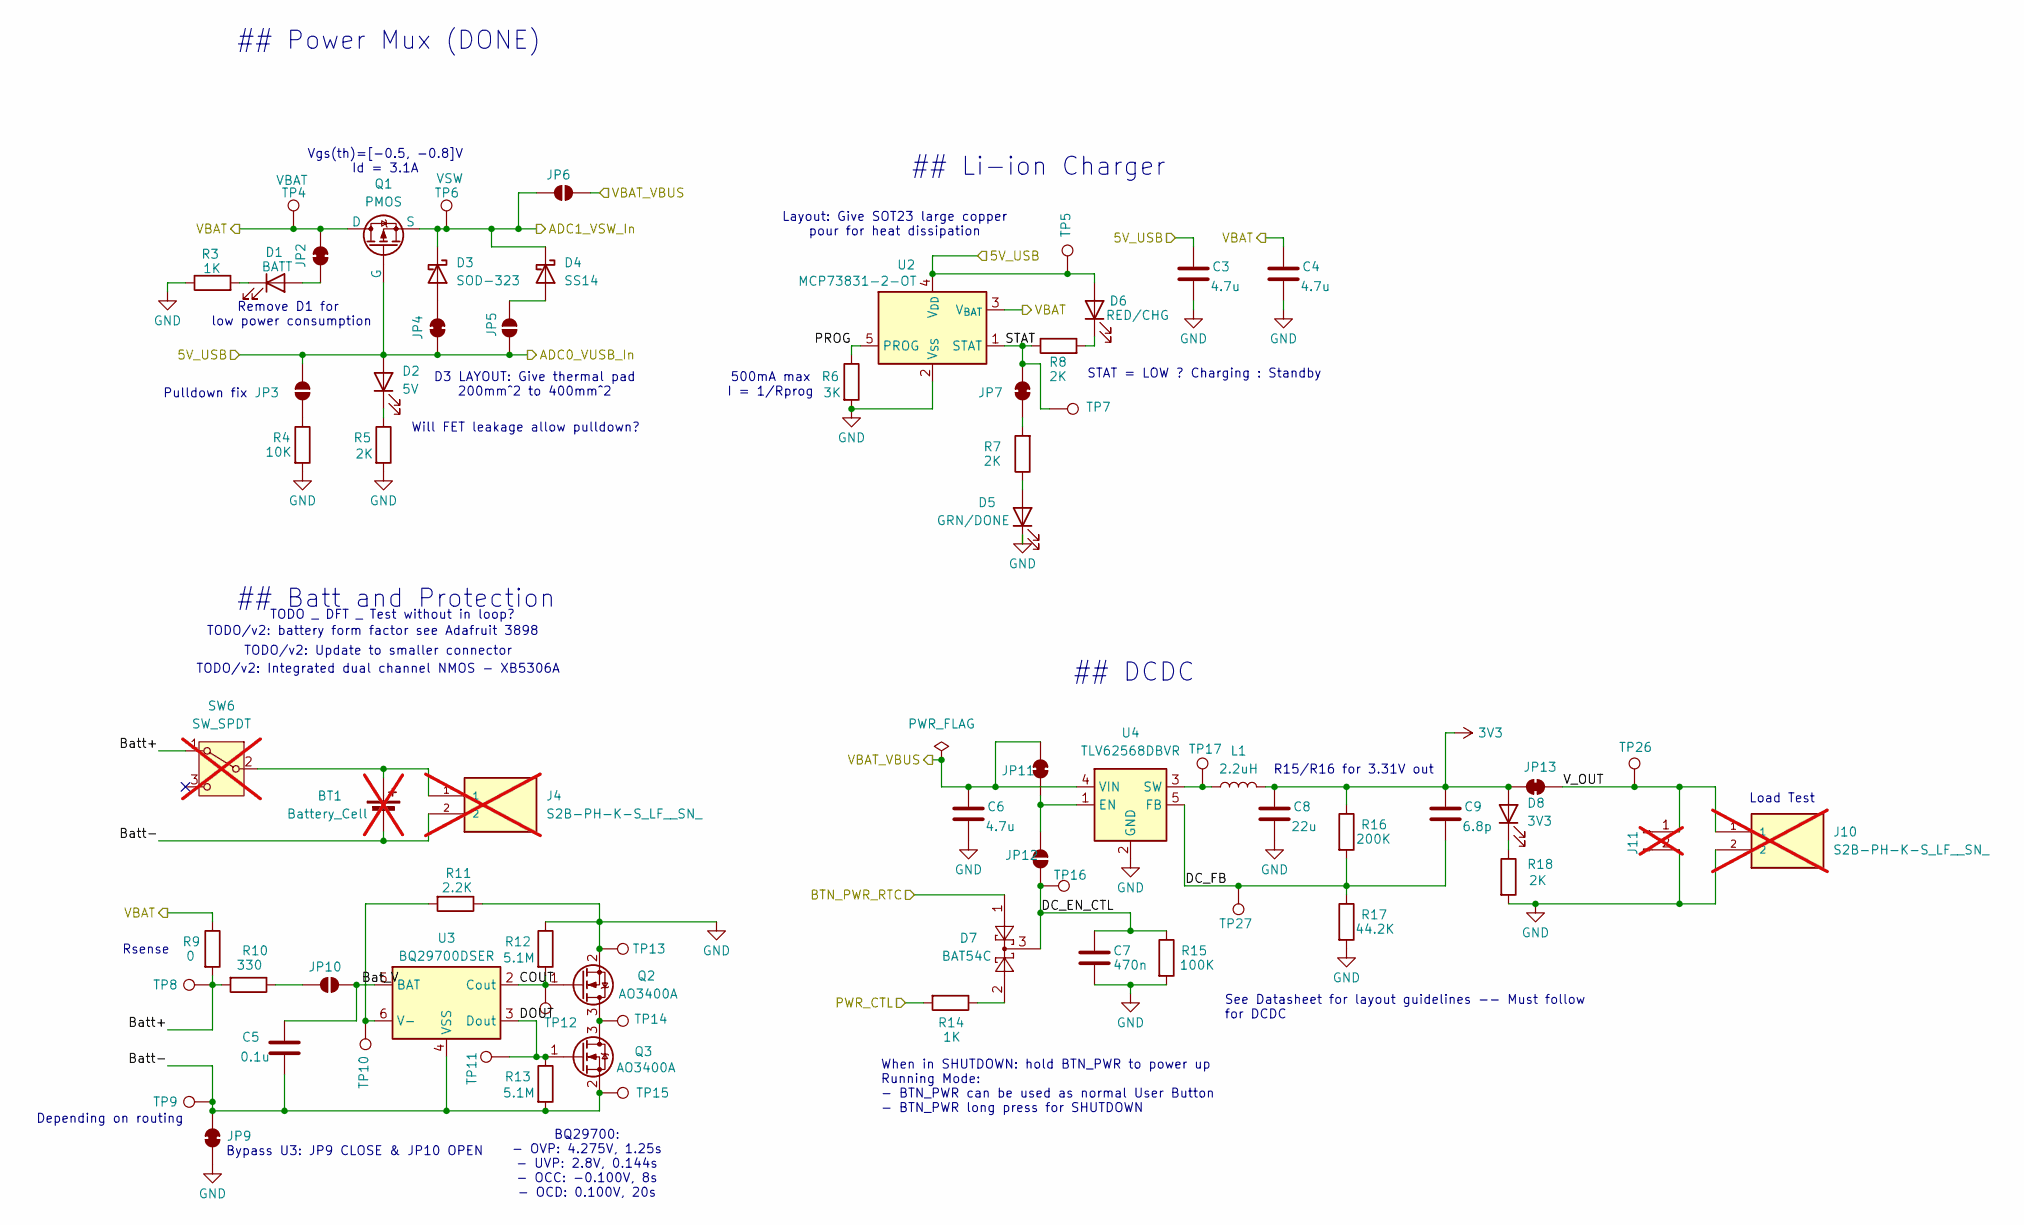
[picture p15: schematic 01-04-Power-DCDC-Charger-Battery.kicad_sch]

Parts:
BT1: Battery_Cell; Battery-Holder-BH-123A_37.5P_1.8D_MH; MPN BH-123A-A1CJ002; not fitted
C3, C4, C6: 4.7u; C_0603_1608Metric_Pad1.08x0.95mm_HandSolder; MPN (Generic)
C5: 0.1u; C_0603_1608Metric_Pad1.08x0.95mm_HandSolder; MPN (Generic)
C7: 470n; C_0603_1608Metric_Pad1.08x0.95mm_HandSolder; MPN (Generic)
C8: 22u; C_0603_1608Metric_Pad1.08x0.95mm_HandSolder; MPN CL10A226MQ8NRNC
C9: 6.8p; C_0603_1608Metric_Pad1.08x0.95mm_HandSolder; MPN (Generic)
D1: BATT; LED_0805_2012Metric; MPN KT-0805G
D2: 5V; LED_0805_2012Metric; MPN KT-0805G
D3: SOD-323; D_SOD-323_HandSoldering; MPN PMEG1020EA,115
D4: SS14; D_SMA; MPN SS14 (Generic)
D5: GRN/DONE; LED_0805_2012Metric; MPN KT-0805G
D6: RED/CHG; LED_0805_2012Metric; MPN NCD0805R1
D7: BAT54C; SOT-23; MPN BAT54CLT1G
D8: 3V3; LED_0805_2012Metric; MPN KT-0805G
J4, J10: S2B-PH-K-S_LF__SN_; JST_PH_S2B-PH-K_1x02_P2.00mm_Horizontal; MPN S2B-PH-K-S; not fitted
J11: Conn_01x02_Pin; PinHeader_1x02_P2.54mm_Vertical; not fitted
JP2, JP4, JP7, JP9, JP11, JP13: SolderJumper_2_Bridged; SolderJumper-2_P1.3mm_Bridged_RoundedPad1.0x1.5mm; MPN (Embedded)
JP3, JP5, JP6, JP10, JP12: SolderJumper_2_Open; SolderJumper-2_P1.3mm_Open_RoundedPad1.0x1.5mm; MPN (Embedded)
L1: 2.2uH; IND_SDER041H-2R2MS; MPN SDER041H-2R2MS
Q1: PMOS; SOT-23; MPN SI2301CDS-T1-GE3
Q2, Q3: AO3400A; SOT-23; MPN AO3400A
R3, R14: 1K; R_0805_2012Metric_Pad1.20x1.40mm_HandSolder; MPN (Generic)
R4: 10K; R_0805_2012Metric_Pad1.20x1.40mm_HandSolder; MPN (Generic)
R5, R7, R8, R18: 2K; R_0805_2012Metric_Pad1.20x1.40mm_HandSolder; MPN (Generic)
R6: 3K; R_0805_2012Metric_Pad1.20x1.40mm_HandSolder; MPN (Generic)
R9: 0; R_0805_2012Metric_Pad1.20x1.40mm_HandSolder; MPN (Generic)
R10: 330; R_0805_2012Metric_Pad1.20x1.40mm_HandSolder; MPN (Generic)
R11: 2.2K; R_0805_2012Metric_Pad1.20x1.40mm_HandSolder; MPN (Generic)
R12, R13: 5.1M; R_0805_2012Metric_Pad1.20x1.40mm_HandSolder; MPN (Generic)
R15: 100K; R_0805_2012Metric_Pad1.20x1.40mm_HandSolder; MPN (Generic)
R16: 200K; R_0805_2012Metric_Pad1.20x1.40mm_HandSolder; MPN (Generic)
R17: 44.2K; R_0805_2012Metric_Pad1.20x1.40mm_HandSolder; MPN (Generic)
SW6: SW_SPDT; SW_E-Switch_EG1271_SPDT; MPN EG1271; not fitted
TP4: VBAT; TestPoint_THTPad_D2.0mm_Drill1.0mm; MPN (Embedded)
TP5: U2_VDD; TestPoint_THTPad_D2.0mm_Drill1.0mm; MPN (Embedded)
TP6: VSW; TestPoint_THTPad_D2.0mm_Drill1.0mm; MPN (Embedded)
TP7: STAT; TestPoint_THTPad_D2.0mm_Drill1.0mm; MPN (Embedded)
TP8: BAT+; TestPoint_THTPad_D2.0mm_Drill1.0mm; MPN (Embedded)
TP9, TP15: BAT-; TestPoint_THTPad_D2.0mm_Drill1.0mm; MPN (Embedded)
TP10: U3_V-; TestPoint_THTPad_D2.0mm_Drill1.0mm; MPN (Embedded)
TP11: DSG; TestPoint_THTPad_D2.0mm_Drill1.0mm; MPN (Embedded)
TP12: CHG; TestPoint_THTPad_D2.0mm_Drill1.0mm; MPN (Embedded)
TP13: GND; TestPoint_THTPad_D2.0mm_Drill1.0mm; MPN (Embedded)
TP14: Q23_D; TestPoint_THTPad_D2.0mm_Drill1.0mm; MPN (Embedded)
TP16: EN_CTL; TestPoint_THTPad_D2.0mm_Drill1.0mm; MPN (Embedded)
TP17: DC_SW; TestPoint_THTPad_D2.0mm_Drill1.0mm; MPN (Embedded)
TP26: LOAD; TestPoint_THTPad_D2.0mm_Drill1.0mm; MPN (Embedded)
TP27: FB; TestPoint_THTPad_D2.0mm_Drill1.0mm; MPN (Embedded)
U2: MCP73831-2-OT; SOT-23-5; MPN MCP73831T-2ACI/OT
U3: BQ29700DSER; WSON-6_1.5x1.5mm_P0.5mm; MPN BQ29700DSER
U4: TLV62568DBVR; SOT-23-5; MPN TLV62568DBVR

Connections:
3V3: C8.1, C9.1, D8.2 (A), JP13.2 (B), L1.2, R16.1; also elsewhere on the board
/MCU-IO/ADC0_VUSB_In: C3.1, D2.2 (A), D6.2 (A), JP3.2 (B), JP4.2 (B), JP5.1 (A), Q1.2 (G), TP5.1, U2.4 (V_{DD}); also elsewhere on the board
/MCU-IO/ADC1_VSW_In: D3.1 (K), D4.1 (K), JP6.2 (B), Q1.3 (S), TP6.1; also elsewhere on the board
/MCU-IO/DCDC_EN: R14.2; also elsewhere on the board
/MCU-IO/IO_Gate: D7.1; also elsewhere on the board
/MCU-IO/VBAT_VBUS: C6.1, JP6.1 (A), JP11.2 (B), U4.4 (VIN); also elsewhere on the board
/Power-DCDC-Charger-Battery/Bat_V: C5.1, JP10.1 (A), U3.5 (BAT)
/Power-DCDC-Charger-Battery/Batt+: R9.2, R10.2, SW6.1 (A), TP8.1
/Power-DCDC-Charger-Battery/Batt-: BT1.2 (-), C5.2, J4.2, JP9.1 (A), Q3.2 (S), R13.2, TP9.1, TP15.1, U3.4 (VSS)
/Power-DCDC-Charger-Battery/COUT: Q2.1 (G), R12.2, TP12.1, U3.2 (Cout)
/Power-DCDC-Charger-Battery/DC_EN_CTL: C7.1, D7.3, JP12.1 (A), R15.1, TP16.1
/Power-DCDC-Charger-Battery/DC_FB: C9.2, R16.2, R17.1, TP27.1, U4.5 (FB)
/Power-DCDC-Charger-Battery/DOUT: Q3.1 (G), R13.1, TP11.1, U3.3 (Dout)
/Power-DCDC-Charger-Battery/PROG: R6.1, U2.5 (PROG)
/Power-DCDC-Charger-Battery/STAT: JP7.2 (B), R8.1, TP7.1, U2.1 (STAT)
/Power-DCDC-Charger-Battery/VBAT: C4.1, JP2.1 (A), Q1.1 (D), R9.1, TP4.1, U2.3 (V_{BAT}); also elsewhere on the board
/Power-DCDC-Charger-Battery/V_OUT: J10.1, J11.1, JP13.1 (A), TP26.1
GND: C3.2, C4.2, C6.2, C7.2, C8.2, D5.1 (K), J10.2, J11.2, JP9.2 (B), Q2.2 (S), R3.1, R4.2, R5.2, R6.2, R11.1, R12.1, R15.2, R17.2, R18.2, TP13.1, U2.2 (V_{SS}), U4.2 (GND); also elsewhere on the board
unnamed: BT1.1 (+), J4.1, SW6.2 (B)
unnamed: D1.2 (A), JP2.2 (B)
unnamed: D1.1 (K), R3.2
unnamed: D2.1 (K), R5.1
unnamed: D3.2 (A), JP4.1 (A)
unnamed: D4.2 (A), JP5.2 (B)
unnamed: D5.2 (A), R7.1
unnamed: D6.1 (K), R8.2
unnamed: D7.2, R14.1
unnamed: D8.1 (K), R18.1
unnamed: JP3.1 (A), R4.1
unnamed: JP7.1 (A), R7.2
unnamed: JP10.2 (B), R10.1
unnamed: JP11.1 (A), JP12.2 (B), U4.1 (EN)
unnamed: Q2.3 (D), Q3.3 (D), TP14.1
unnamed: R11.2, TP10.1, U3.6 (V-)
unnamed: L1.1, TP17.1, U4.3 (SW)

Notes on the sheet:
Depending on routing
## DCDC
BQ29700: - OVP: 4.275V, 1.25s - UVP: 2.8V, 0.144s - OCC: -0.100V, 8s - OCD: 0.100V, 20s
D3 LAYOUT: Give thermal pad 200mm^2 to 400mm^2
TODO/v2: Update to smaller connector
Layout: Give SOT23 large copper pour for heat dissipation
R15/R16 for 3.31V out
Load Test
Pulldown fix
Vgs(th)=[-0.5, -0.8]V Id = 3.1A
When in SHUTDOWN: hold BTN_PWR to power up Running Mode: - BTN_PWR can be used as normal User Button - BTN_PWR long press for SHUTDOWN
TODO _ DFT _ Test without in loop?
See Datasheet for layout guidelines -- Must follow for DCDC
STAT = LOW ? Charging : Standby
TODO/v2: battery form factor see Adafruit 3898
Bypass U3: JP9 CLOSE & JP10 OPEN
## Power Mux (DONE)
## Li-ion Charger
Remove D1 for low power consumption
Will FET leakage allow pulldown?
TODO/v2: Integrated dual channel NMOS - XB5306A
## Batt and Protection
500mA max I = 1/Rprog
Rsense

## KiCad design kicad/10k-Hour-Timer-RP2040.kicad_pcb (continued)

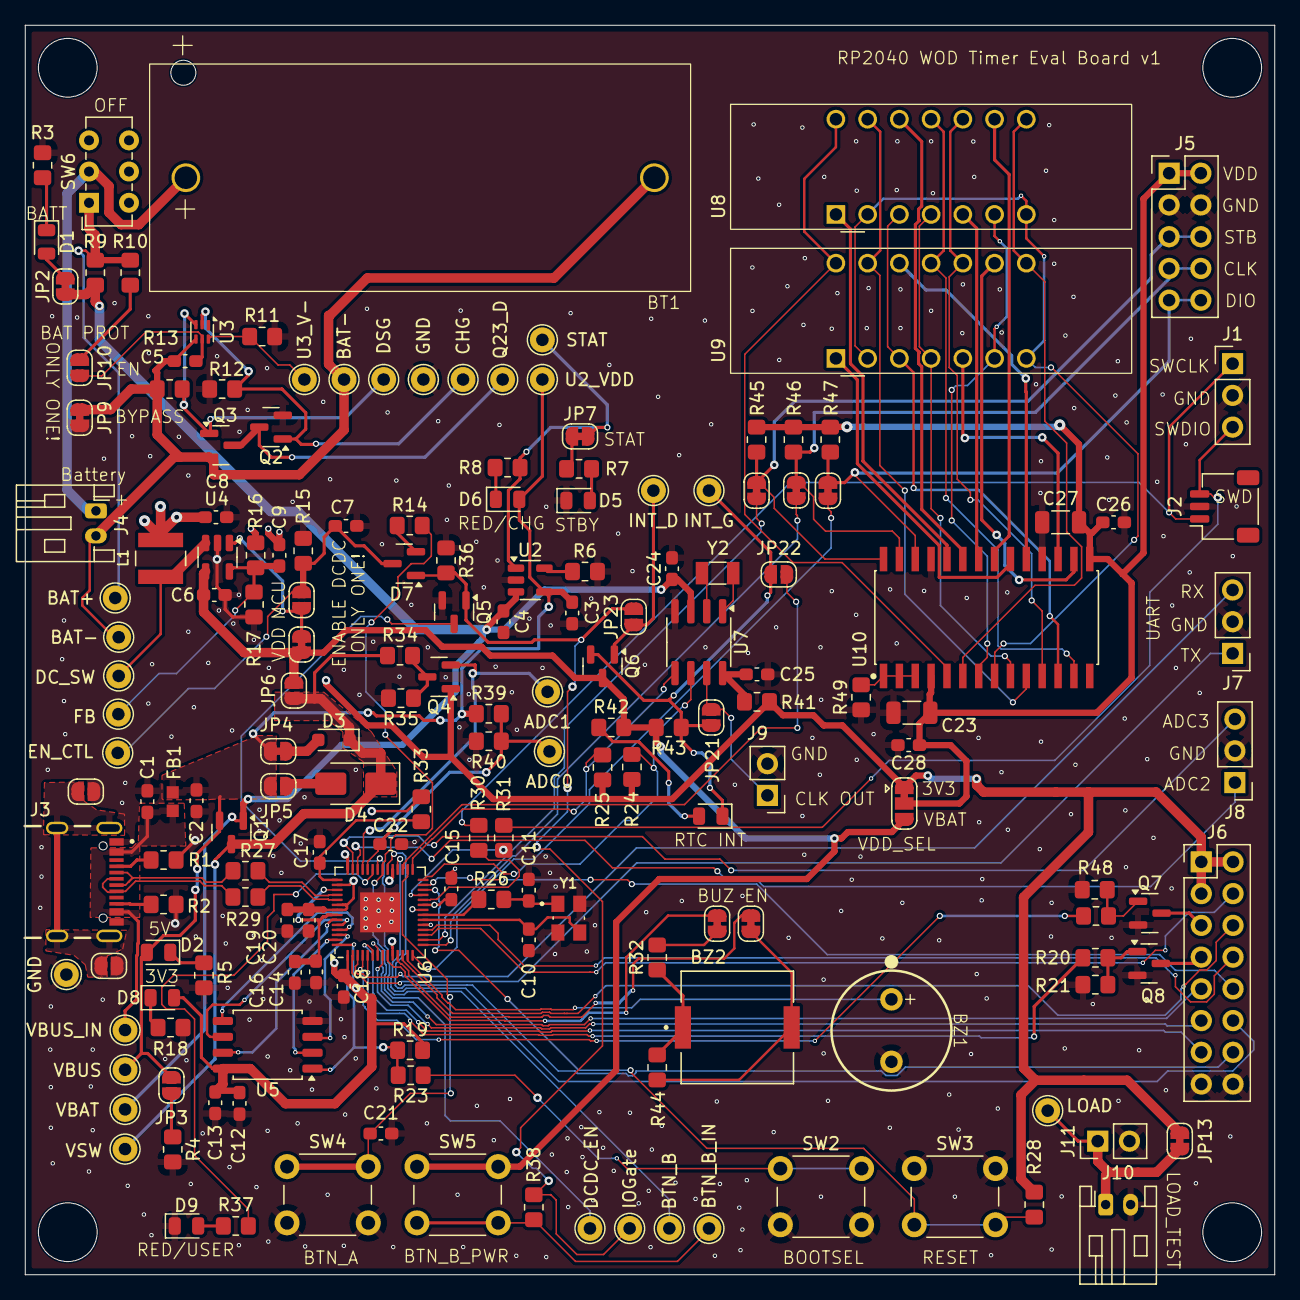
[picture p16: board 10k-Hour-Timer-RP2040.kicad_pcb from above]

Board: 4 copper layers, 100.0 x 100.0 mm, 180 parts (0 on the bottom side), 128 nets.

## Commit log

2025-07-06 Initial commit - 10k-Hour-Timer-RP2040 project
    - KiCad schematic and PCB design files
    - Project structure with datasheets and firmware directories
    - README with project overview
    [01-04-Power-DCDC-Charger-Battery.kicad_sch, 05-07_MCU-LED-Driver-Displays.kicad_sch, 10k-Hour-Timer-RP2040.kicad_pcb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]
2025-07-06 3d model imports
    [05-07_MCU-LED-Driver-Displays.kicad_sch, 10k-Hour-Timer-RP2040.kicad_pcb, 10k-Hour-Timer-RP2040.kicad_sch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]
2025-07-07 added charger and power mux
    [01-04-Power-DCDC-Charger-Battery.kicad_sch, 10k-Hour-Timer-RP2040.kicad_pcb, 10k-Hour-Timer-RP2040.kicad_sch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]
2025-07-08 battery charger and protection
    [01-04-Power-DCDC-Charger-Battery.kicad_sch, 10k-Hour-Timer-RP2040.kicad_pcb, BQ29700DSER.step]
2025-07-09 battery protection and connector
    [01-04-Power-DCDC-Charger-Battery.kicad_sch, S2B-PH-K-S_LF__SN_.step]
2025-07-09 dc dc start
    [01-04-Power-DCDC-Charger-Battery.kicad_sch, 05-07_MCU-LED-Driver-Displays.kicad_sch, 10k-Hour-Timer-RP2040.kicad_pcb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]
2025-07-10 working on dcdc
    [01-04-Power-DCDC-Charger-Battery.kicad_sch]
2025-07-10 dcdc enable and swd
    [01-04-Power-DCDC-Charger-Battery.kicad_sch, 05-07_MCU-LED-Driver-Displays.kicad_sch, 10k-Hour-Timer-RP2040.kicad_pcb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]
2025-07-13 rp2040 chip start
    [01-04-Power-DCDC-Charger-Battery.kicad_sch, 05-07_MCU-LED-Driver-Displays.kicad_sch, 10k-Hour-Timer-RP2040.kicad_sch]
2025-07-13 mcu periphs
    [01-04-Power-DCDC-Charger-Battery.kicad_sch, 05-07_MCU-LED-Driver-Displays.kicad_sch, 10k-Hour-Timer-RP2040.kicad_pcb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]
2025-07-14 clock input pins for internal rtc
    [05-07_MCU-LED-Driver-Displays.kicad_sch]
2025-07-14 added 32.768 oscillator
    [01-04-Power-DCDC-Charger-Battery.kicad_sch, 05-07_MCU-LED-Driver-Displays.kicad_sch]
2025-07-15 low speed xtal added
    [01-04-Power-DCDC-Charger-Battery.kicad_sch, 05-07_MCU-LED-Driver-Displays.kicad_sch, 10k-Hour-Timer-RP2040.kicad_sch]
2025-07-15 external RTC start
    [05-07_MCU-LED-Driver-Displays.kicad_sch]
2025-07-15 rtc research
    [05-07_MCU-LED-Driver-Displays.kicad_sch]
2025-07-16 rtc hardware
    [01-04-Power-DCDC-Charger-Battery.kicad_sch, 05-07_MCU-LED-Driver-Displays.kicad_sch, 10k-Hour-Timer-RP2040.kicad_sch]
2025-07-16 rtc additions
    [05-07_MCU-LED-Driver-Displays.kicad_sch]
2025-07-18 DR ✅ SYS-01-Power-Mux
    [01-04-Power-DCDC-Charger-Battery.kicad_sch, 05-07_MCU-LED-Driver-Displays.kicad_sch, 10k-Hour-Timer-RP2040.kicad_pcb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]
2025-07-18 DR SYS-02-DCDC ✅
    [01-04-Power-DCDC-Charger-Battery.kicad_sch, 05-07_MCU-LED-Driver-Displays.kicad_sch, 10k-Hour-Timer-RP2040.kicad_pcb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]
2025-07-18 led indicator silks
    [10k-Hour-Timer-RP2040.kicad_pcb]
2025-07-19 DR SYS-03 Charger ✅
    [01-04-Power-DCDC-Charger-Battery.kicad_sch, 10k-Hour-Timer-RP2040.kicad_pcb]
2025-07-19 charger pcb update
    [01-04-Power-DCDC-Charger-Battery.kicad_sch, 05-07_MCU-LED-Driver-Displays.kicad_sch, 10k-Hour-Timer-RP2040.kicad_pcb]
2025-07-20 DR SYS-04-Battery Protect ✅
    [01-04-Power-DCDC-Charger-Battery.kicad_sch, 05-07_MCU-LED-Driver-Displays.kicad_sch, 10k-Hour-Timer-RP2040.kicad_pcb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]
2025-07-20 DR SYS-05-MCU XTAL
    [01-04-Power-DCDC-Charger-Battery.kicad_sch, 05-07_MCU-LED-Driver-Displays.kicad_sch, 10k-Hour-Timer-RP2040.kicad_pcb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]
2025-07-21 DR SYS-06-MCU-IO ✅
    [05-07_MCU-LED-Driver-Displays.kicad_sch, 10k-Hour-Timer-RP2040.kicad_pcb, 10k-Hour-Timer-RP2040.kicad_sch]
2025-07-22 buzzer edits
    [BQ29700DSER.step, PKMCS0909E4000-R1.step]
2025-07-26 rtc new sheet, pullups
    [01-04-Power-DCDC-Charger-Battery.kicad_sch, 05-07_MCU-LED-Driver-Displays.kicad_sch, 10k-Hour-Timer-RP2040.kicad_sch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]
2025-07-27 pre ERC
    [01-04-Power-DCDC-Charger-Battery.kicad_sch, 05-07_MCU-LED-Driver-Displays.kicad_sch, 10k-Hour-Timer-RP2040.kicad_pcb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]
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2025-07-28 buzzer fp, power mux layout
    [01-04-Power-DCDC-Charger-Battery.kicad_sch, 05-07_MCU-LED-Driver-Displays.kicad_sch, 10k-Hour-Timer-RP2040.kicad_pcb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]
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2025-08-02 layout - 7seg display
    [05-07_MCU-LED-Driver-Displays.kicad_sch, 10k-Hour-Timer-RP2040.kicad_pcb, 10k-Hour-Timer-RP2040.kicad_sch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]
2025-08-02 layout - footprints update - may have corrupted kicad_sch project lib
    [01-04-Power-DCDC-Charger-Battery.kicad_sch, 05-07_MCU-LED-Driver-Displays.kicad_sch, 10k-Hour-Timer-RP2040.kicad_pcb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]
2025-08-02 floorplanning - fixed 7seg symbol issue
    [10k-Hour-Timer-RP2040.kicad_pcb, TM1638_Display.kicad_sch]
2025-08-04 start routing diff pairs
    [05-07_MCU-LED-Driver-Displays.kicad_sch, 10k-Hour-Timer-RP2040.kicad_pcb]
2025-08-04 changed usb port, prepare first bom export
    [01-04-Power-DCDC-Charger-Battery.kicad_sch, 05-07_MCU-LED-Driver-Displays.kicad_sch, 10k-Hour-Timer-RP2040.csv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]
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2025-08-11 routing - 3v3 net
    [01-04-Power-DCDC-Charger-Battery.kicad_sch, 10k-Hour-Timer-RP2040.kicad_pcb]
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2025-08-17 DRC to zero errors - still need to check FPs
    [10k-Hour-Timer-RP2040.kicad_pcb, 10k-Hour-Timer-RP2040.kicad_sch, TM1638_Display.kicad_sch]
2025-08-17 prep for FP changes
    [10k-Hour-Timer-RP2040.kicad_pcb]
2025-08-17 updated FPs, ready for final DR before fab
    [10k-Hour-Timer-RP2040.kicad_pcb]
2026-02-08 production files for PCBWay initial - BOM manually edited for PCBA
    [01-04-Power-DCDC-Charger-Battery.kicad_sch, 05-07_MCU-LED-Driver-Displays.kicad_sch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]
2026-02-12 fabrication files, after edits for pcbway 2-12
    [05-07_MCU-LED-Driver-Displays.kicad_sch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]
2026-03-22 prep for release v1 as built from PCBWay
    [Quotation T-X9W732328A-2sets-10k-Hour-Timer-RP2040_BOM_MOUNTING_ONLY(2026-02-15).xls]
